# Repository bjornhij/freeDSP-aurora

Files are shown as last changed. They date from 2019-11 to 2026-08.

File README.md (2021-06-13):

FreeDSP logo

# freeDSP aurora

An open source and open hardware [freeDSP](https://freedsp.github.io) board based on ADAU1452 with 8 analog I/O, S/P-DIF I/O, ADAT I/O, USB Audio, WiFi, Bluetooth.

It supports various and convenient physical addons and multiple software plugins, and is controlled by web interface.

## Main features

* Analog Devices ADAU1452, 294.912 MHz, 32-bit SigmaDSP
	* 6144 SIMD instructions per sample @ 48kHz fs
	* 40kWords of data RAM
	* 800ms digital audio delay pool @ 48kHz fs
	* 8 stereo ASRCs with 139dB DNR
* XMOS XE216-512-TQ128 for multichannel bidirectional audio streaming
* ESP32 for WiFi or Bluetooth control
* AKM AK4458 32bit-DAC
* AKM AK5558 32bit-ADC
* Supporting sample rates between 44.1kHz and 192kHz
* 8 analog balanced input channels, +6dBu
* 8 analog balanced output channels, +6dBu
* S/P-DIF input and output
* ADAT input and output
* Wordclock input and output
* Support for display, rotary encoder, volume potentiometer, temperature sensor, PWM controlled fan, IR sensor
* One freeDSP expansion header
* USB Audio Class 2 Bidirectional streaming with 8 channels in and 8 channels out, full-duplex. Works with ASIO driver under Windows 10 and driverless under macOS and Linux.
* Realtime control software over WiFi or Bluetooth available under an open source license
* THD DAC: -103dB @ 1kHz, 0dBfs, fs=48kHz
* THD ADC: -101dB @ 1kHz, 0dBfs, fs=48kHz
* Latency: 1.125ms (talkthrough ADC->DSP->DAC)
* Board dimensions: 110mm x 110mm

MAIN COORDINATOR: [dspverden](https://github.com/dspverden)

## Contributing

**Please take care on which branch you're currently working!**

Branches:

- *master* - this branch always holds the latest released revision
- *develop* - this is the develop branch with new features. Please base your patches on this branch.

[Build instructions](BUILDING.md) | [Addons](ADDONS/README.md) | [User Documentation](DOCUMENTATION/)

## License
<br />This work is licensed under a <a rel="license" href="http://creativecommons.org/licenses/by-sa/4.0/">Creative Commons Attribution-ShareAlike 4.0 International License</a>.

## Links

- [Buy Aurora board and addons](https://auverdion.de/)
- [freeDSP](https://freedsp.github.io)
- [Kickstarter campaign](https://www.kickstarter.com/projects/auverdion/freedsp-aurora-dsp)
- [DIYAudio forum (english)](https://www.diyaudio.com/forums/digital-line-level/334055-freedsp-aurora-dsp-8-os-usb-audio-dif-adat-bluetooth-wifi-contro.html)
- [DIYHifi forum (german, features)](https://www.diy-hifi-forum.eu/forum/showthread.php?18572-freeDSP-aurora-Der-Feature-Thread)
- [DIYHifi forum (german, specs)](https://www.diy-hifi-forum.eu/forum/showthread.php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)
- [Youtube tutorials](https://www.youtube.com/channel/UCGmSGSIjvFPSlGyMbqJgFxw)
- [ADAU1452 at Analog Devices](https://www.analog.com/en/products/adau1452.html)
- [ESP32 at Espressif](https://www.espressif.com/en/products/socs/esp32/overview)
- [XMOS XE216-512-TQ128 datasheet](https://www.xmos.com/file/xe216-512-tq128-datasheet)
- [AKM 4458](https://www.akm.com/us/en/products/audio/audio-dac/ak4458vn/)
- [AKM 5558](https://www.akm.com/us/en/products/audio/audio-adc/ak5558vn/)

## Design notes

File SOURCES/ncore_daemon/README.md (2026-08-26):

# Ncore / aurora daemon

Python-brug tussen de freeDSP aurora (serieel), Hypex Ncore (GPIO), het scherm, en Home Assistant. Geen Volumio, geen Docker. Home Assistant draait **elders**; deze Pi 4 toont de UI fullscreen en bedient de amp.

## Kale installatie (Raspberry Pi 4)

### 1. Imager

Raspberry Pi Imager, **Raspberry Pi OS (64-bit) met desktop** (niet Lite — Chromium-kiosk heeft een GUI nodig):

- hostname: `hypex-amp`
- SSH aan
- gebruiker: `ncore` (niet `volumio`)
- wifi of ethernet

Eerste boot:

```bash
sudo apt update && sudo apt full-upgrade -y
sudo raspi-config
```

In raspi-config: **System Options → Auto Login** (desktop). **I2C niet aanzetten** als AMPON op BCM 3 blijft: dat is I2C1 SCL (`GPIO3`).

### 2. Code en service

Kopieer deze map naar `/home/ncore/ncore_daemon` (git clone van de repo en `cd SOURCES/ncore_daemon`, of rsync).

```bash
cd /home/ncore/ncore_daemon
chmod +x scripts/install.sh scripts/ha-kiosk.sh
./scripts/install.sh
```

Dat zet een venv, `config.yaml`, systemd `ncore-daemon` en Chromium-kiosk autostart. Log daarna opnieuw in zodat de groepen `gpio`, `dialout`, `input` en `video` gelden.

### 3. Scherm herkennen

Op een draaiende Pi (ook de oude):

```bash
cat /proc/device-tree/model; echo
ls /sys/class/backlight/
ls /sys/class/drm/
grep -hE 'dtoverlay|display|hdmi|dsi|lcd' /boot/firmware/config.txt /boot/config.txt 2>/dev/null
```

- Map `rpi_backlight` = official 7" DSI. **Dit is de huidige hypex-amp** (Pi 4B 1.2). Amp aan zet backlight op 80, amp uit op 0.
- `hdmi_force_hotplug=1` kan naast DSI in config.txt staan (tweede HDMI of oude workaround). Ontbreekt `rpi_backlight`, dan HDMI via `vcgencmd display_power`.
- Geen `/sys/class/drm/` op oude Volumio/legacy-graphics is normaal; op verse Pi OS desktop bestaat die map wél.

### 4. Hardware in `config.yaml`

**Serial (aurora)** — niet het Mac-pad `/dev/tty.MALS`:

```bash
ls /dev/serial/by-id /dev/ttyUSB* 2>/dev/null
```

Zet `serial_port` op de `by-id`-symlink (blijft gelijk na reboot).

**IR:**

```bash
python3 - <<'PY'
from evdev import InputDevice, list_devices
for path in list_devices():
    d = InputDevice(path)
    print(path, d.name)
PY
```

Zet `ir_device_name` op een uniek stuk van die naam. USB-IR verschijnt vanzelf; GPIO-IR: `dtoverlay=gpio-ir` in `/boot/firmware/config.txt`.

**GPIO:** BCM 3, HIGH = amp uit. Eerste keer `dry_run: true` of speakers los tot de pin klopt.

**Home Assistant:**

```yaml
ha_kiosk_url: "http://homeassistant.local:8123"
ha_webhook_url: "http://homeassistant.local:8123/api/webhook/ncore_updated"
```

Kiosk-login eenmalig in Chromium. Als het scherm leeg blijft op Wayland: raspi-config → Advanced → Wayland → **X11**, reboot.

```bash
sudo systemctl restart ncore-daemon
curl -s http://127.0.0.1:9090/status
```

`serial_ok` / `gpio_ok` / `ir_ok` moeten kloppen. Debug-UI: `http://hypex-amp.local:9090/`.

## Home Assistant (op de server)

Kopieer `homeassistant/ncore_amp.yaml` naar `configuration.yaml`. Webhook-id: `ncore_updated`. Entiteit: `media_player.ncore_amp` (aan/uit, volume, bron — geen muziekstreaming).

### Kiosk-login (eenmaal, of nooit)

Chromium bewaart de sessie in `~/.config/chromium`. Eerste keer: aparte HA-user `kiosk` (geen admin), inloggen, **Keep me logged in**.

Zonder login-scherm: trusted networks + één user voor het Pi-IP. Alleen `allow_bypass_login` zonder `trusted_users` logt automatisch in als er **één** HA-user is; bij meerdere users krijg je een keuzelijst. Koppel het IP daarom aan het kiosk-user-id:

```yaml
homeassistant:
  auth_providers:
    - type: trusted_networks
      trusted_networks:
        - 192.168.1.50/32
      trusted_users:
        192.168.1.50:
          - 0123456789abcdef0123456789abcdef
      allow_bypass_login: true
    - type: homeassistant
```

User-id: Instellingen → Personen → user openen; id staat in de URL (`/config/users/<id>`). `homeassistant` als tweede provider laten staan, anders kun je vanaf andere IP’s niet meer met wachtwoord inloggen. Daarna HA herstarten.

Niet het Chromium-profiel wissen en niet als admin in de kiosk inloggen.

## Volume-bescherming

- Harde cap `max_volume` (80). HA 100% = die cap.
- Boot: amp uit, DSP naar `power_on_volume` (9).
- Power-on: `min(laatste volume, power_on_restore_cap)` (20) naar de DSP, **daarna** GPIO aan.
- Power-off: eerst mute op de DSP, dan GPIO uit (en scherm uit).
- Omhoog alleen in stappen van 1 (`volume_step_interval_ms` 150). IR-repeat 150 ms.
- Volume 0 stuurt wel mute naar de DSP.

## Dry-run / tests (Mac)

```bash
python3 -m ncore_daemon --dry-run
pip install -r requirements-dev.txt
python -m pytest
```

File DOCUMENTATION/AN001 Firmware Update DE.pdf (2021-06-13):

# FIRMWARE UPDATE FREEDSP-AURORA

auverdion | 1

## REVISIONSÜBERSICHT

Revision | Beschreibung | Datum
v1.0.0 | Initial Version | 09 Feb 2020
v1.1.0 | WebOTA hinzugefügt | 26 Feb 2020
v2.1.0 | Empfehlung zum Presetexport hinzugefügt | 20 Jul 2020
auverdion | 2

Revisionsübersicht | 2
Wichtige Information | 4
Update der Firmware via USB | 5
Update vorbereiten | 5
Firmware hochladen | 6
Update der Firmware über webOTA | 12
Hochladen der Firmware | 12
Haftungsausschluss | 14
auverdion | 3

## WICHTIGE INFORMATION

Das freeDSP-Aurora-Board kann Signale erzeugen, die Dein Audiogerät beschädigen können. Bitte lies dieses Application Note und das Handbuch sorgfältig, bevor Du mit der Arbeit mit Deinem Board beginnst. Passe alle Hardware-Einstellungen an und konfiguriere Deine Software, bevor Du ein Audiogerät an freeDSP-aurora anschließt. Beginne immer mit der geringsten Lautstärke an Deinem Verstärker und erhöhe den Pegel langsam, um das Risiko einer Beschädigung Deines Audiosystems zu verringern.

Insbesondere die Installation von Alpha- und Betaversionen kann zu einem fehlerhaften Verhalten führen. Die Installation erfolgt auf eigenes Risiko.

FreeDSP-aurora wird Dir wie gesehen zur Verfügung gestellt. Auverdion gibt keine ausdrücklichen oder stillschweigenden Garantien in Bezug auf seine Funktionalität, Funktionsfähigkeit oder Nutzung, einschließlich, aber nicht beschränkt auf stillschweigende Garantien der Marktgängigkeit, der Eignung für einen bestimmten Zweck oder Rechtsverletzungen. Wir lehnen ausdrücklich jegliche Haftung für direkte, indirekte, Folge-, Neben- oder Sonderschäden ab, einschließlich, aber nicht beschränkt auf Umsatzeinbußen, entgangenen Gewinn, Verluste infolge von Betriebsunterbrechungen oder Datenverlust, unabhängig von der Art der Klage oder der Rechtstheorie, nach der die Haftung geltend gemacht werden kann, selbst wenn wir über die Möglichkeit oder Wahrscheinlichkeit solcher Schäden informiert wurden. Funktionen und Spezifikationen können ohne vorherige Ankündigung geändert werden.

Bitte beachte, dass freeDSP-aurora ein Open-Source-Projekt ist. Da freeDSP-aurora sehr flexibel ist, sind viele Anwendungen möglich. Fragen und neue Ideen können online mit anderen Nutzern diskutiert werden. Bitte verwende das Digital Line Level Subforum @ diyAudio.com oder das auverdion Subforum @ www.diy-hifi-forum.eu, um mit anderen Personen in Kontakt zu treten, die mit freeDSP-aurora arbeiten. Bitte erstelle nur dann individuelle Themen für Dein Anliegen, wenn Du Dein Problem in den vorhandenen Themen nicht findest. Einige Fragen können durch sorgfältiges Lesen dieses Handbuchs beantwortet werden.

auverdion | 4

## UPDATE DER FIRMWARE VIA USB

Dieses Kapitel führt Dich durch alle Schritte, um ein Firmwareupdate über eine USB-Verbindung durchzuführen. Das Update selbst wird durch ein Skript durchgeführt.

UPDATE VORBEREITEN

Für das Aktualisieren der Firmware benötigst Du ein USB2Serial-Modul basierend auf einem FTx232- oder CP2102N-Modul, z.B. https://www.ftdichip.com/Products/Modules/DevelopmentModules.htm#FT2232H_Mini oder ähnlich. Bitte vergewissere Dich, daß Dein Modul mit einer Spannung von 3.3V arbeitet. Module mit +5V Spannung können Deinen freeDSP-Aurora beschädigen.
Ggfs. Musst Du noch einen Treiber für Dein USB2Serial-Modul installieren. Bitte lies hierzu das Handbuch Deines Moduls.

Wenn Du ein Update von Version 2.x.x ausführen willst, exportiere bitte zunächst Deine Presets, damit Du diese nach dem Update wieder importieren kannst.

auverdion | 5

FIRMWARE HOCHLADEN

Um eine neue Firmware auf Deinen freeDSP-Aurora hochzuladen, gehe wie folgt vor:
1. Lade das neueste Release von github: https://github.com/freeDSP/freeDSP-aurora Wenn Du eine Alpha- oder Betaversion (Preview-Versionen) installieren möchtest, musst Du eventuell in den entsprechenden Featurezweig wechseln, indem Du diesen im Dropdown-Menu Branch auswählst, z.B. feature/develop und anschliessend auf Clone or download klickst und Download ZIP auswählst.

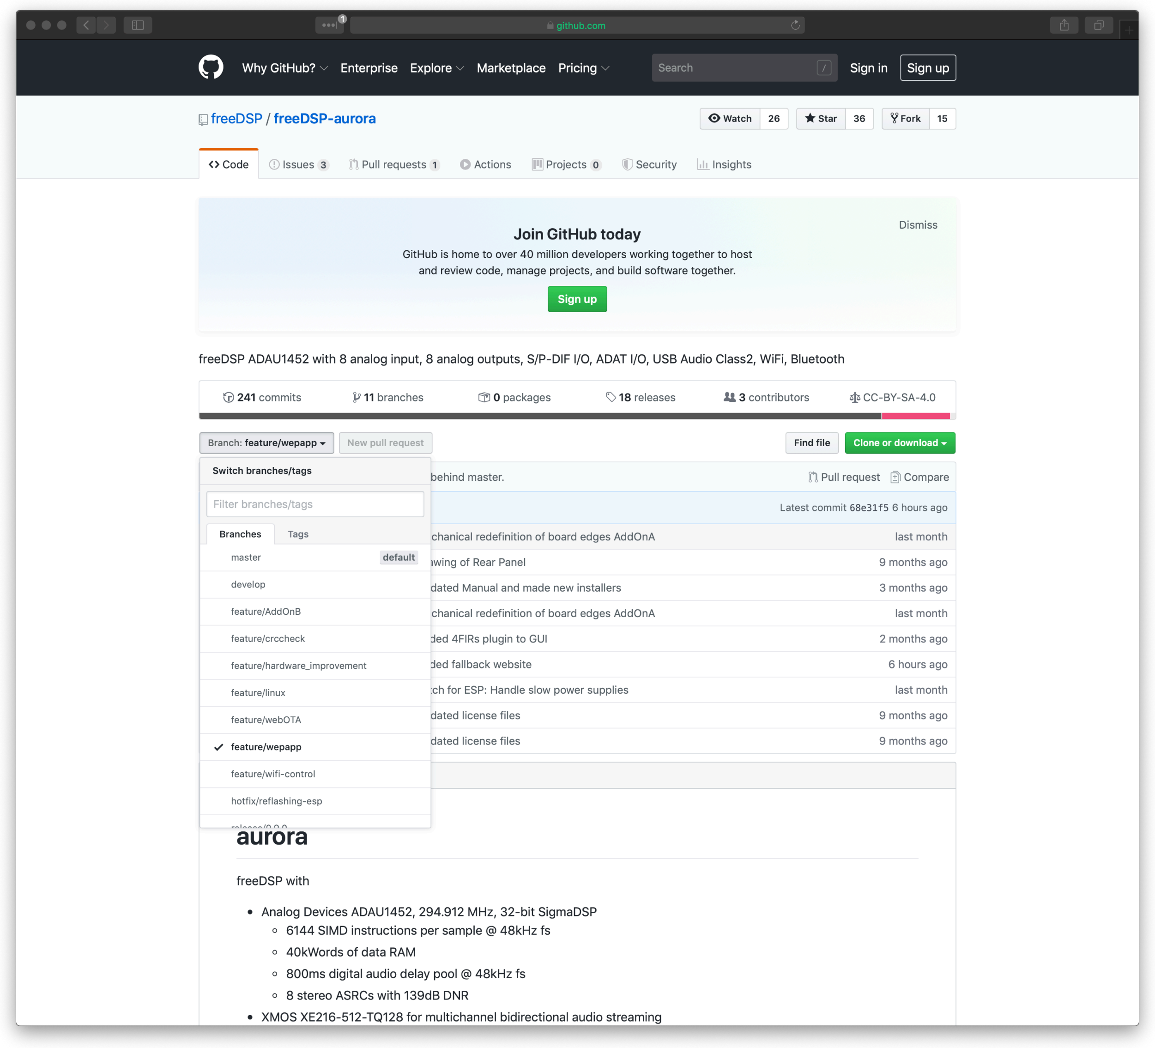
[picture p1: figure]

auverdion | 6

2. Entpacke die heruntergeladene zip-Datei (sofern Dein Computer dies nicht selbstständig erledigt).
3. Schalte Deinen freeDSP-aurora aus.
4. Installiere einen Jumper oder stelle eine Verbindung zwischen Pin 5 und 6 von X504 her. Das Update-Tool wird Dich an diesen Jumper erinnern.

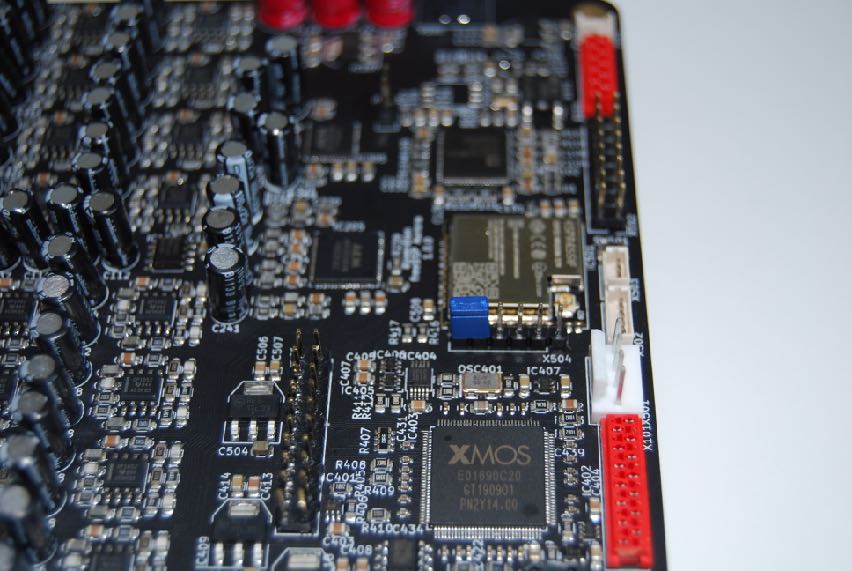
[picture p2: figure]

auverdion | 7

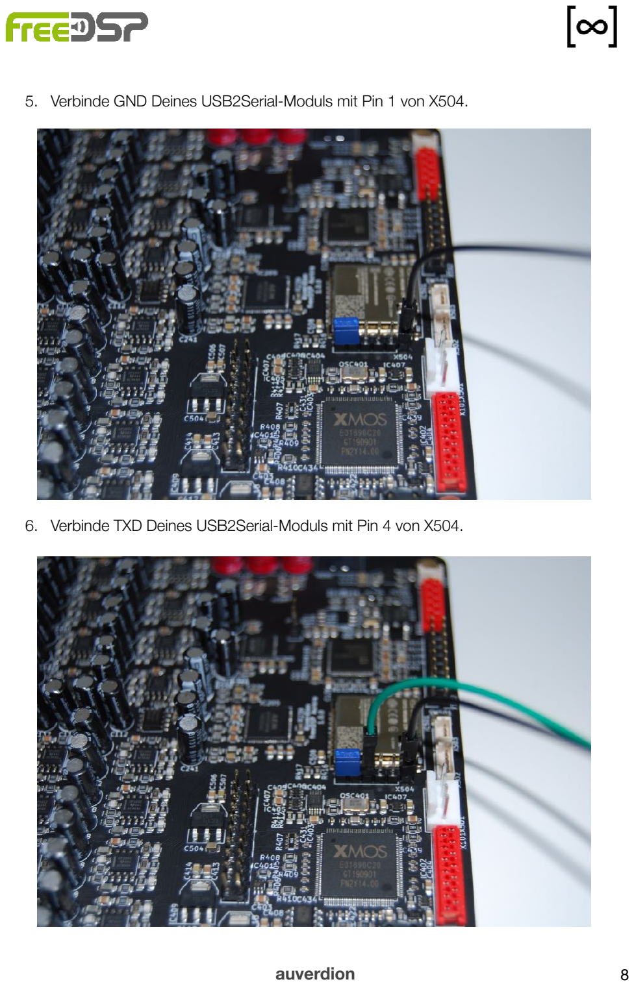
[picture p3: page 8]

5. Verbinde GND Deines USB2Serial-Moduls mit Pin 1 von X504.
6. Verbinde TXD Deines USB2Serial-Moduls mit Pin 4 von X504.
auverdion | 8

7. Verbinde RXD Deines USB2Serial-Moduls mit Pin 3 von X504.

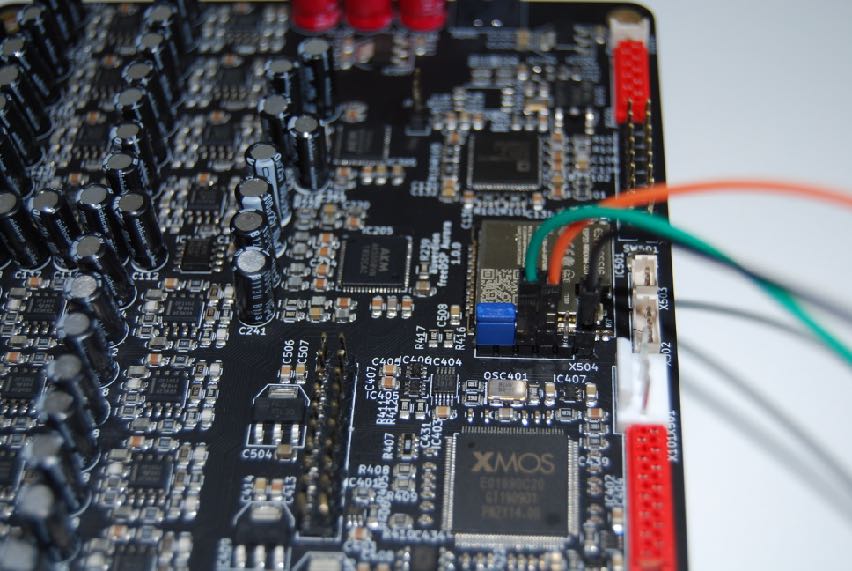
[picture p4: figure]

8. Verbinde Dein USB2Serial-Modul mit Deinem Computer.
9. Schalte freeDSP-Aurora ein.
10. Öffne ein Terminal (Eingabeaufforderung) and wechsle in das Skript-Verzeichnis durch Eingabe von
cd <path_to_repository>/SOURCES/WEBAPP/ESP32/updater
11. Unter macOs kann es sein, dass Du das Updateskript ausführbar machen musst. Gibt dazu ein:
chmod +x update.sh
12. Unter macOS starte das Skript mit ./update.sh <your_com_port>.
Dabei musst Du <your_com_port> durch den Namen Deines USB2Serial-Adapters
ersetzen, z.B. /dev/cu.usbserial-FTRXGG930.
13. Unter Windows gibts Du update.bat <your_com_port> ein.
Dabei musst Du <your_com_port> durch den Namen Deines USB2Serial-Adapters ersetzten, z.B. COM3.
auverdion | 9

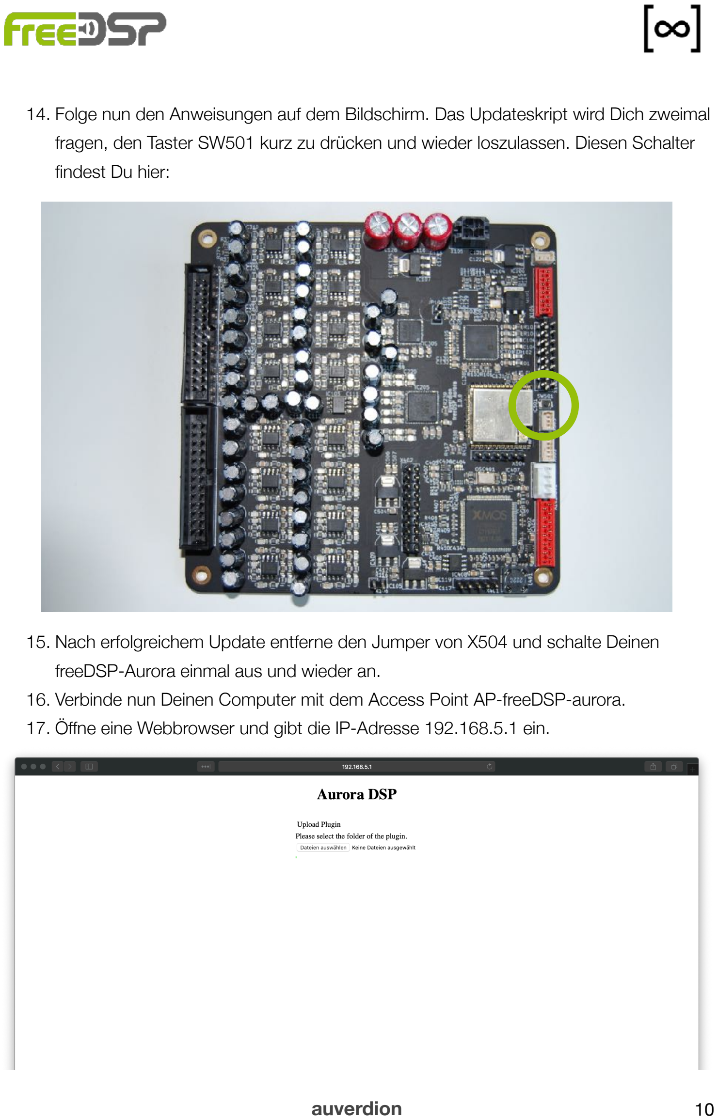
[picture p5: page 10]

14. Folge nun den Anweisungen auf dem Bildschirm. Das Updateskript wird Dich zweimal fragen, den Taster SW501 kurz zu drücken und wieder loszulassen. Diesen Schalter findest Du hier:
15. Nach erfolgreichem Update entferne den Jumper von X504 und schalte Deinen freeDSP-Aurora einmal aus und wieder an.
16. Verbinde nun Deinen Computer mit dem Access Point AP-freeDSP-aurora.
17. Öffne eine Webbrowser und gibt die IP-Adresse 192.168.5.1 ein.
auverdion | 10

18. Klicke nun auf Dateien auswählen und wähle das Verzeichnis mit Deinem Plugin aus. Wichtig: Bitte wähle nur das Verzeichnis, nicht eine Datei in dem Verzeichnis.
Du findest die Plugins im Verzeichnis <path_to_repository>/SOURCES/

WEBAPP/plugins

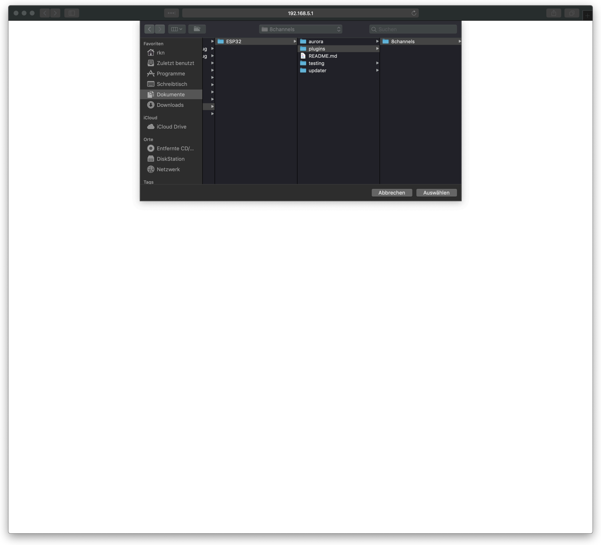
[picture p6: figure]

19. Es wird das gewählte Plugin installiert.
20. Nach erfolgreichem Update startest Du Deinen freeDSP-Aurora neu, verbindest Dich mit dem Access Point AP-freeDSP-aurora und gibst die Adresse 192.168.5.1 in Deinem Webbrowser ein. Du siehts nun das Webinterface Deines gewählten Plugins und kannst damit beginnen, freeDSP-Aurora für Deine Anwendung zu konfiguriere.
auverdion | 11

## UPDATE DER FIRMWARE ÜBER WEBOTA

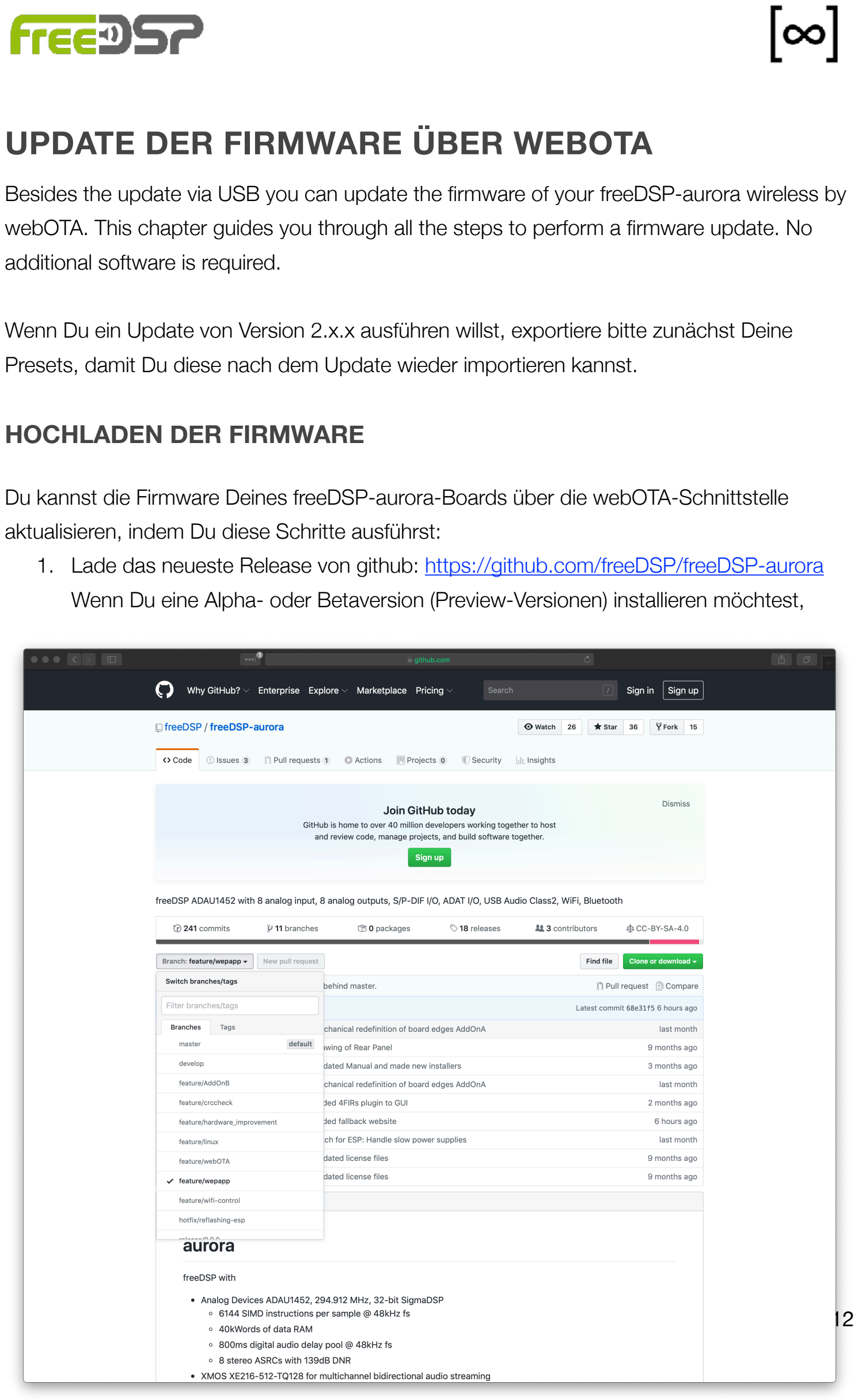
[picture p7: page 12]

Besides the update via USB you can update the firmware of your freeDSP-aurora wireless by webOTA. This chapter guides you through all the steps to perform a firmware update. No additional software is required.

Wenn Du ein Update von Version 2.x.x ausführen willst, exportiere bitte zunächst Deine Presets, damit Du diese nach dem Update wieder importieren kannst.

HOCHLADEN DER FIRMWARE

Du kannst die Firmware Deines freeDSP-aurora-Boards über die webOTA-Schnittstelle aktualisieren, indem Du diese Schritte ausführst:
1. Lade das neueste Release von github: https://github.com/freeDSP/freeDSP-aurora Wenn Du eine Alpha- oder Betaversion (Preview-Versionen) installieren möchtest,
auverdion | 12

musst Du eventuell in den entsprechenden Featurezweig wechseln, indem Du diesen im Dropdown-Menu Branch auswählst, z.B. feature/develop und anschliessend auf Clone or download klickst und Download ZIP auswählst. Die heruntegeladene ZIP-Datei musst Du noch entpacken, falls Dein Computer das nicht selbständig macht.
2. Verbinde Deinen Computer mit dem WiFi-Access-Point AP-freeDSP-aurora.
3. Öffne einen Webbrowser und gib die URL http://192.168.5.1/webota ein.
4. Alternativ kannst Du Deinen Computer mit dem gleichen lokalen WiFi-Netzwerk verbinden, mit dem auch Dein freeDSP-Aurora verbunden ist, und die IP 192.168.5.1 durch die IP ersetzen, die Dein Board von Deinem Router erhalten hat.
5. Klicke auf die Schaltfläche, um die Firmware-Binärdatei von Ihrer Festplatte auszuwählen. Der Dateiname der Firmware ist üblicherweise
aurora.ino.esp32.bin. Die Firmware auf dem neuesten Stand findest Du in

<path_to_repository>/SOURCES/WEBAPP/ESP32/updater
6. Sobald Du eine Datei ausgewählt hast wird die neue Firmware auf Dein Board hochgeladen. Nach dem erfolgreichen Update erhältst Du eine Benachrichtigung und Dein freeDSP-aurora-Board wird anschliessend automatisch neu gestartet.
7. Verbinde Dich mit dem Access Point AP-freeDSP-aurora und gebe http://192.168.5.1/fallback im URL-Feld Deines Browsers ein.
8. Installiere nun das Plugin neu.
9. Dein freeDSP-aurora ist nun auf dem neuesten Stand.
auverdion | 13

## HAFTUNGSAUSSCHLUSS

Alle Produkte, Produktspezifikationen und Daten können ohne Vorankündigung geändert werden, um die Zuverlässigkeit, Funktion oder das Design zu verbessern.
Auverdion, seine Tochtergesellschaften, Vertreter und Mitarbeiter sowie alle Personen, die in seinem oder ihrem Namen handeln, lehnen jegliche Haftung für Fehler, Ungenauigkeiten oder Unvollständigkeiten ab, die in einem Datenblatt, Handbuch, einer Anwendungsnotiz oder einem anderen Dokument zu einem Produkt enthalten sind.
Diese Baugruppe ist nur für den Einsatz in Musikwiedergabegeräten vorgesehen. Es werden keine Angaben zur Eignung für andere Zwecke gemacht. Sofern nicht anders angegeben, beziehen sich die angegebenen Spezifikationen nur auf diese Baugruppe. Die Verantwortung für die Überprüfung der Leistung, Sicherheit, Zuverlässigkeit und Einhaltung der gesetzlichen Normen von Endprodukten mit dieser Baugruppe liegt beim Hersteller des Endprodukts.

Auverdion gibt keine ausdrücklichen oder stillschweigenden Garantien in Bezug auf seine Funktionalität, Funktionsfähigkeit oder Nutzung, einschließlich, aber nicht beschränkt auf stillschweigende Garantien der Marktgängigkeit, der Eignung für einen bestimmten Zweck oder Rechtsverletzung. Wir lehnen ausdrücklich jegliche Haftung für direkte, indirekte, Folge-, Neben- oder Sonderschäden ab, einschließlich, aber nicht beschränkt auf Umsatzeinbußen, entgangenen Gewinn, Verluste infolge von Betriebsunterbrechungen oder Datenverlust, unabhängig von der Art der Klage oder der Rechtstheorie, nach der die Haftung geltend gemacht werden kann, selbst wenn wir über die Möglichkeit oder Wahrscheinlichkeit solcher Schäden informiert wurden.

Die Verwendung von Auverdion-Produkten in lebenserhaltenden Geräten oder Geräten, deren Ausfall erwartbar zu Verletzungen oder zum Tod führen kann, ist nicht zulässig.

auverdion | 14

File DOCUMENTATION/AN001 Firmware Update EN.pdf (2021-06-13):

# FIRMWARE UPDATE FREEDSP-AURORA

auverdion | 1

## REVISION HISTORY

Revision | Description | Date
v1.0.0 | Initial Version | 09 Feb 2020
v1.1.0 | Added webOTA | 26 Feb 2020
v2.1.0 | Added hint for preset export | 20 Jul 20
auverdion | 2

Revision History | 2
Important Information | 4
Updating the Firmware via USB | 5
Preparing for Update | 5
Uploading the Firmware | 6
Updating the Firmware via webOTA | 12
Uploading the Firmware | 12
Disclaimer | 14
auverdion | 3

## IMPORTANT INFORMATION

The freeDSP-aurora board might generate signals that may damage your audio equipment. Please read and understand this manual before starting to work with your board. Adjust all hardware settings and configure your software before connecting any audio equipment to freeDSP-aurora. Always start with low volume on your amplifier and slowly increase the level to reduce the risk of damaging your audio system.

Especially the installation of alpha and beta versions can lead to incorrect behavior. The installation is at your own risk.

freeDSP-aurora is provided to you ‘as is’. Auverdion makes no express or implied warranties whatsoever with respect to its functionality, operability, or use, including, without limitation, any implied warranties of merchantability, fitness for a particular purpose, or infringement. We expressly disclaim any liability whatsoever for any direct, indirect, consequential, incidental or special damages, including, without limitation, lost revenues, lost profits, losses resulting from business interruption or loss of data regardless of the form of action or legal theory under which the liability may be asserted, even if advised of the possibility or likelihood of such damages. Features and specifications might change without prior notice.

Please keep in mind that freeDSP-aurora is an open-source project. Because freeDSP-aurora is very flexible, many applications are possible. Questions and new ideas can be discussed online with other DIYers. Please use the Digital Line Level subforum @ diyAudio.com or the auverdion subforum @ www.diy-hifi-forum.eu to connect with other people working with freeDSP-aurora. Please create individual threads for your topics only if you cannot find your issue in the existing threads. Some questions can be answered by carefully reading this manual.

auverdion | 4

## UPDATING THE FIRMWARE VIA USB

This chapter guides you through all the steps to perform a firmware update via an USB connection. The update itself will be done by a script.

PREPARING FOR UPDATE

For updating the firmware you need an USB2Serial module based on a FTx232 or CP2102N module, e.g.
https://www.ftdichip.com/Products/Modules/DevelopmentModules.htm#FT2232H_Mini or similar. Please make sure that your module works with a voltage of +3.3V. Modules with +5V voltage can damage your freeDSP-Aurora.
You may need to install a driver for your USB2Serial module. Please read the manual of your module.

If you are updating from version 2.x.x please export your presets first and import them after the update again.

auverdion | 5

UPLOADING THE FIRMWARE

For uploading a new firmware to your freeDSP-aurora do the following steps:
1. Download the latest release from github: https://github.com/freeDSP/freeDSP-aurora If you want to install a alpha or beta version (preview versions) instead you may have to switch to the right feature branch by selecting it in the branch drop down menu, e.g. feature/develop. Then click on Clone or download and select Download ZIP.

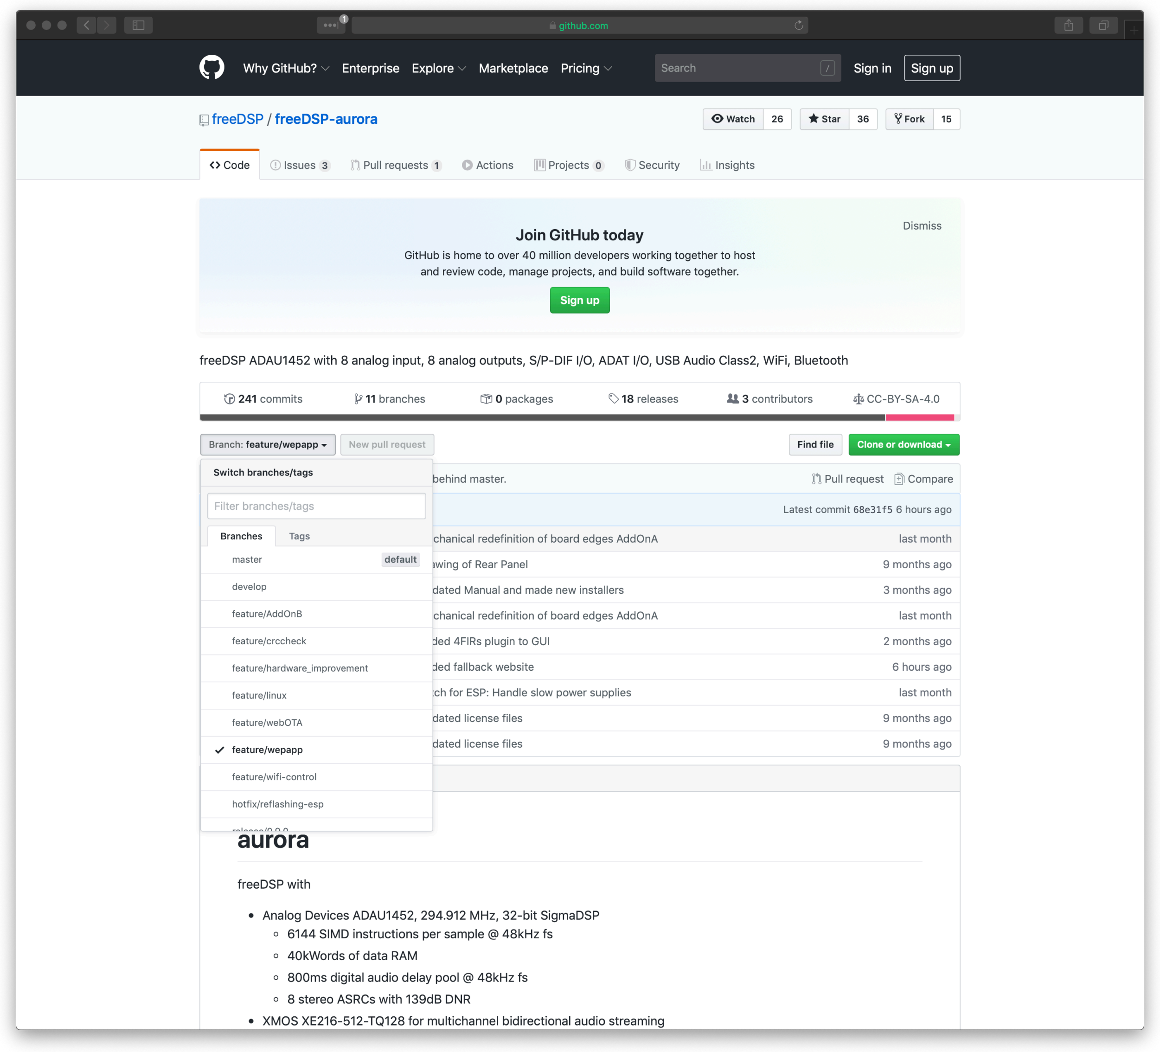
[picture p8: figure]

2. Unzip the downloaded zip file (if your computer does not do this by itself).
3. Power off your freeDSP-aurora module.
auverdion | 6

4. Install a jumper or make a connection between pin 5 and 6 of X504. The update tool will remind you of this jumper.


auverdion | 7

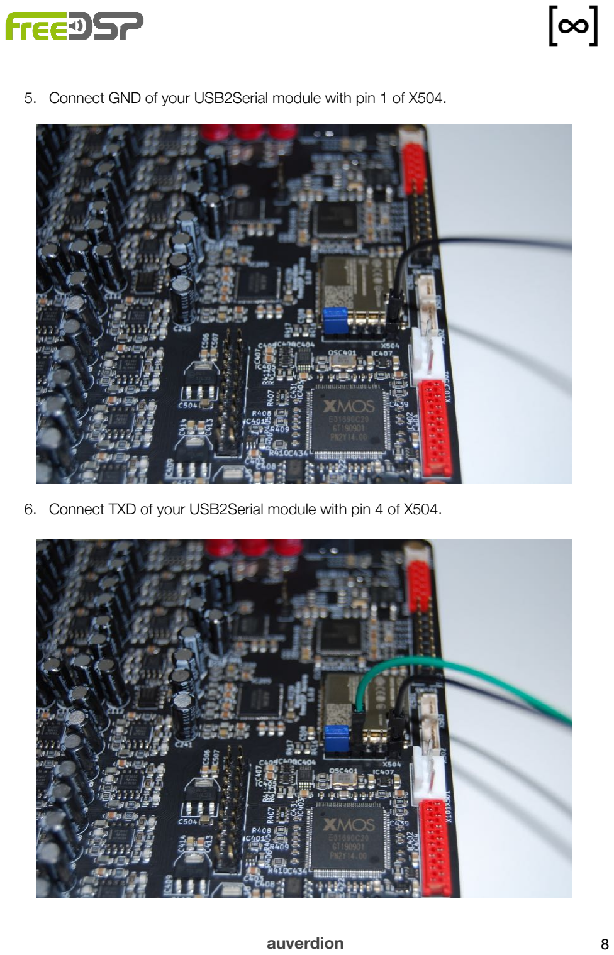
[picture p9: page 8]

5. Connect GND of your USB2Serial module with pin 1 of X504.
6. Connect TXD of your USB2Serial module with pin 4 of X504.
auverdion | 8

7. Connect RXD of your USB2Serial module with pin 3 of X504.


8. Connect your USB2Serial module with your computer.
9. Power up your freeDSP-aurora.
10. Open a terminal (command prompt) and change to script directory by entering
cd <path_to_repository>/SOURCES/WEBAPP/ESP32/updater
11. On macOs you may have to make the update script executable by entering
chmod +x update.sh
12. Under macOS start the update scrip by ./update.sh <your_com_port>. Replace <your_com_port> by the name of your USB2Serial module, e.g.
/dev/cu.usbserial-FTRXGG930.
13. Under Windows start the update scrip by update.bat <your_com_port>. Replace <your_com_port> by the name of your USB2Serial module, e.g. COM3.
auverdion | 9

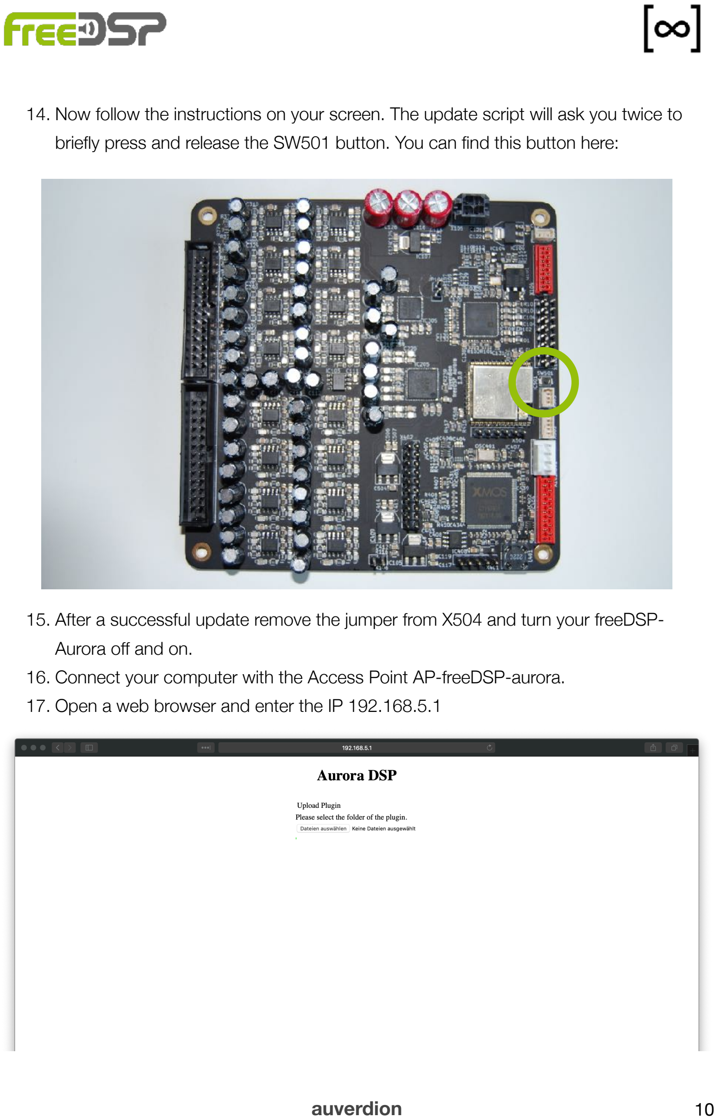
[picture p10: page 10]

14. Now follow the instructions on your screen. The update script will ask you twice to briefly press and release the SW501 button. You can find this button here:
15. After a successful update remove the jumper from X504 and turn your freeDSP-Aurora off and on.
16. Connect your computer with the Access Point AP-freeDSP-aurora.
17. Open a web browser and enter the IP 192.168.5.1
auverdion | 10

18. Click now on Select files and select the directory of the plugin you want to install. Important: You have to select the directory name not any file inside this directory. You
will find the plugins here: <path_to_repository>/SOURCES/WEBAPP/plugins

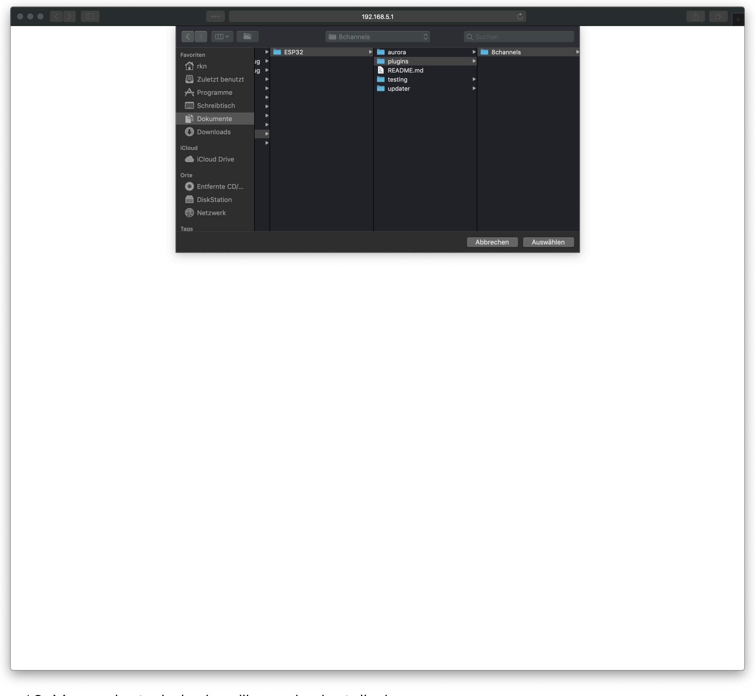
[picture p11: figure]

19. Your selected plugin will now be installed.
20. After successful installation restart your freeDSP-Aurora, reconnect to access point AP-freeDSP-aurora and in your web browser type in the address 192.168.5.1. You will see now the web interface of your selected plugin. You can now start to configure freeDSP-Aurora for your application.
auverdion | 11

## UPDATING THE FIRMWARE VIA WEBOTA

Besides the update via USB you can update the firmware of your freeDSP-aurora wireless by webOTA. This chapter guides you through all the steps to perform a firmware update. No additional software is required.

If you are updating from version 2.x.x please export your presets first and import them after the update again.

UPLOADING THE FIRMWARE

For uploading a new firmware to your freeDSP-aurora do the following steps:
1. Download the latest release from github: https://github.com/freeDSP/freeDSP-aurora If you want to install a alpha or beta version (preview versions) instead you may have

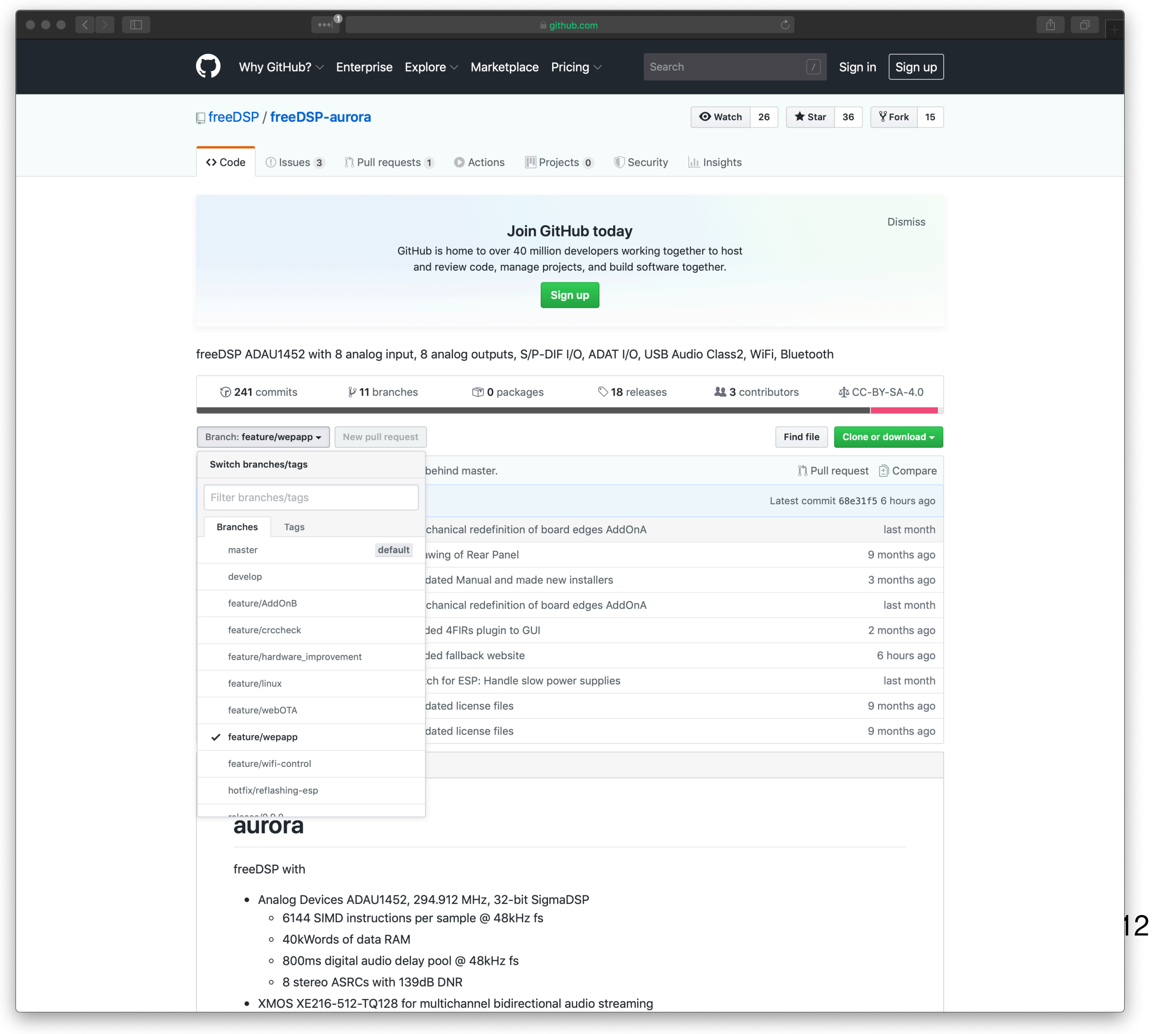
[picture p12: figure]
auverdion

to switch to the right feature branch by selecting it in the branch drop down menu, e.g. feature/develop. Then click on Clone or download and select Download ZIP.
2. Unzip the downloaded zip file (if your computer does not do this by itself).
3. Connect you computer with the WiFi access point AP-freeDSP-aurora.
4. Open web browser and type in the URL http://192.168.5.1/webota
5. Alternatively you can connect you computer to the same local WiFi network your freeDSP-aurora is connected to and replace the ip 192.168.5.1 by the ip your board got from your router.
6. Click on the button to select the firmware binary from your hard disk. The filename of the firmware is usually aurora.ino.esp32.bin. You can find the latest binary in

<path_to_repository>/SOURCES/WEBAPP/ESP32/updater
7. Once you have selected a file the update process starts. The new binary will now be uploaded to your board. After a successful update you will see a message box and afterwards your freeDSP-aurora board will restart.
8. Connect to the Access Point AP-freeDSP-aurora and enter http://192.168.5.1/fallback (http://192.168.5.1/fallback) in the URL field of your browser.
9. Reinstall your plugin now.
10. Your freeDSP-aurora is updated now.
auverdion | 13

## DISCLAIMER

All products, product specifications and data are subject to change without notice to improve reliability, function or design or otherwise.
Auverdion, its affiliates, agents, and employees, and all persons acting on its or their behalf, disclaim any and all liability for any errors, inaccuracies or incompleteness contained in any datasheet, manual, application note or any other document relating to any product.
This subassembly is designed for use in music reproduction equipment only. No representations are made as to fitness for other uses. Except where noted otherwise any specifications given pertain to this subassembly only. Responsibility for verifying the performance, safety, reliability and compliance with legal standards of end products using this subassembly falls to the manufacturer of said end product.

Auverdion makes no express or implied warranties whatsoever with respect to its functionality, operability, or use, including, without limitation, any implied warranties of merchantability, fitness for a particular purpose, or infringement. We expressly disclaim any liability whatsoever for any direct, indirect, consequential, incidental or special damages, including, without limitation, lost revenues, lost profits, losses resulting from business interruption or loss of data regardless of the form of action or legal theory under which the liability may be asserted, even if advised of the possibility or likelihood of such damages.

Life support policy: Use of auverdion products in life support equipment or equipment whose failure can reasonably be expected to result in injury or death is not permitted.

auverdion | 14

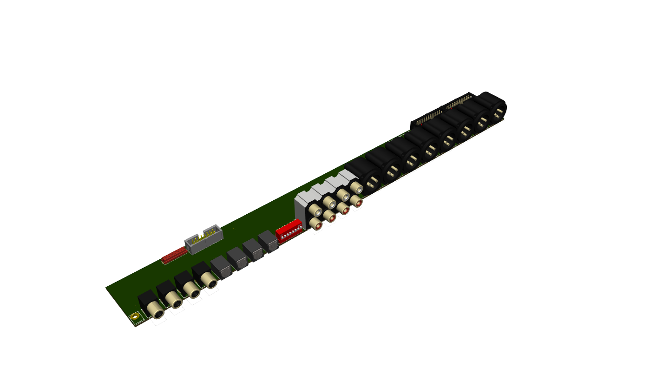
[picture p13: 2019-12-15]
ADDONS/IO/AddOnB-A1.png

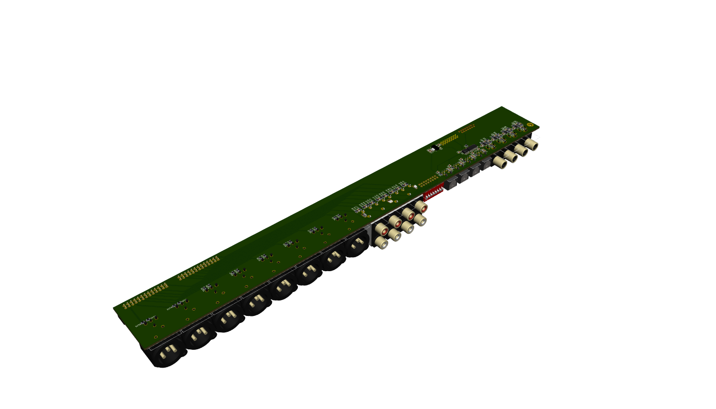
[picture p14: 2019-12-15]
ADDONS/IO/AddOnB-A2.png

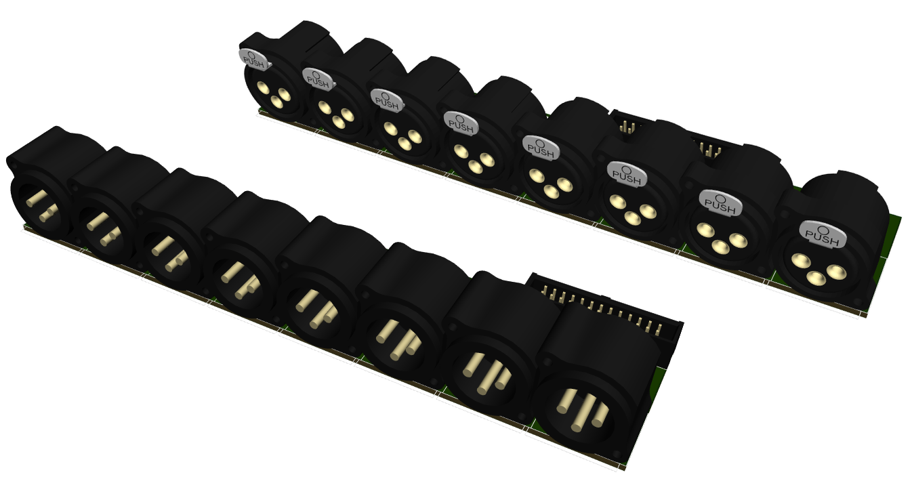
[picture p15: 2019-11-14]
ADDONS/AddOnD/AddOnD_A_B.png

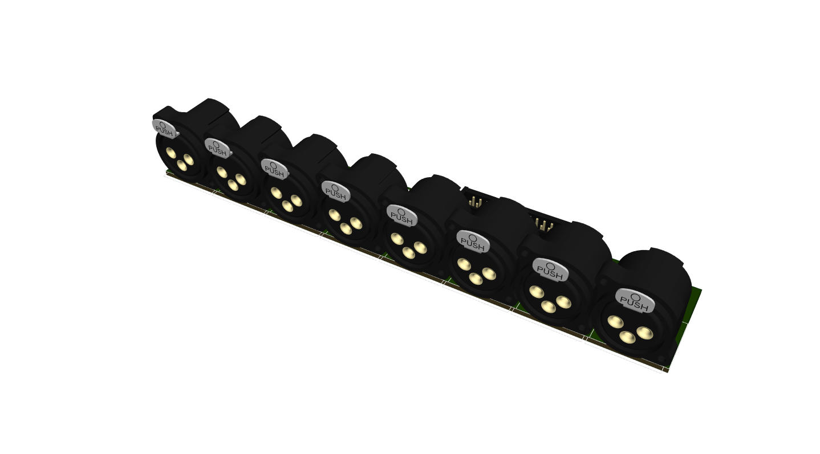
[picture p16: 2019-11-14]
ADDONS/AddOnD/KICAD/Board B/AddOnD.png

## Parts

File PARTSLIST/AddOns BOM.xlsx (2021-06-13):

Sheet: AddOnA
AddOn A rev 1.0.0
Reference | Qty | Footprint | Value1 | Value2 | Manufacturer | pn
B1, B2 | 2 | Montagewinkel
C17 | 1 | C0805-X7R | 10n0 | 10% 50V X7R | Yageo | CC0805KRX7R9BB103
C5, C6, C101 | 3 | C0805-X7R | 100p | 5% 50V C0G/NP0 | Kemet | C0805C101J5GACTU
C1, C2, C3, C4, C7, C24, C109, C113 | 8 | C0805-X7R | 100n | 5% 50V X7R | Kemet | C0805C104K5RACTU
D1 | 1 | D_0603_1608Metric |  |  | Littelfuse Inc. | PESD0603-240
IC1 | 1 | SOT23-5 |  |  | ON Semiconductor | FIN1002M5X
IC6 | 1 | SOIC8_3.9x4.9mm_Pitch1.27mm |  |  | Texas Instruments | PCA9536DR
IC101 | 1 | SOIC-16_3.9x9.9mm_P1.27mm |  |  | Texas Instruments | SN74HC251DR
L101 | 1 | C0805-X7R |  |  | Taiyo Yuden | LBR2012T470K
P1 | 1 | RK09K1110-20 |  |  | Alps | RK09K1110A0J
R1 | 1 | C0805-RES | 91R0 | 1% 0.125W Thick | Yageo | RC0805FR-0791RL
R2 | 1 | C0805-RES | 820R | 1% 0.125W Thick | Yageo | RC0805FR-07820RL
R3, R4, R5 | 3 | C0805-RES | 470R | 1% 0.125W Thick | Yageo | RC0805FR-07470RL
R6, R29 | 2 | C0805-RES | 33R0 | 1% 0.125W Thick | Yageo | RC0805FR-0733RL
R8, R10 | 2 | C0805-RES | 100K | 1% 0.125W Thick | Yageo | RC0805FR-07100KL
R11, R12, R13, R14 | 4 | C0805-RES | 47K0 | 1% 0.125W Thick | Yageo | RC0805FR-0747KL
R25 | 1 | C0805-RES | 10K0 | 1% 0.125W Thick | Yageo | RC0805FR-0710KL
R101, R102 | 2 | C0805-RES | 68R0 | 1% 0.125W Thin | Panasonic Electronic Components | ERA-6AED680V
R7, R9, R117 | 3 | C0805-RES | 100R | 1% 0.25W Thin | Stackpole Electronics Inc | RNCP0805FTD100R
R118 | 1 | C0805-RES | 220K | 1% 0.125W Thick | Yageo | RC0805FR-07220KL
SW1, SW2 | 2 | GEMINI_A |  |  | TE Connectivity Alcoswitch | A203MD9AB04
X1, X3 | 2 | PJRAN1X1U01AUX |  |  | Switchcraft Inc. | PJRAN1X1U01AUX
X2 | 1 | NC3FAH |  |  | Neutrik | NC3FAH1
X4 | 1 | Molex_PicoBlade_530470310 |  |  | Molex | 530470310
X5 | 1 | MM-14G | MicroMatch-14 | - | TE Connectivity AMP Connectors | 1-215079-4
X6 | 1 | IDC2x8_Pitch2.54mm |  |  | On Shore Technology Inc. | 302-S161
X7 | 1 | PLT133_T10W |  |  | Everlight Electronics Co Ltd | PLT133/T10W
X8 | 1 | USB_B | USB_B | horizontal | On Shore Technology Inc. | USB-B1HSB6
X9 | 1 | PinHeader_1x05_P2.54mm_Vertical |  |  | Sullins Connector Solutions | PRPC005SAAN-RC
X101 | 1 | NC3MAH |  |  | Neutrik | NC3MAH-0
X110 | 1 | PLR135_T10 |  |  | Everlight Electronics Co Ltd | PLR135/T10
X114, X115 | 2 | IDC26 | IDC26 |  | Bud Industries | BC-32677

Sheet: AddOnB
AddOn B rev 1.0.0
Reference | Qty | Footprint | Value1 | Value2 | Manufacturer | pn
Board A
C17, C18, C19, C20 | 4 | C0805-X7R | 10n0 | 10% 50V X7R | Yageo | CC0805KRX7R9BB103
C21, C23 | 2 | C0805-X7R | 10u0 | 20% 25V X5R | Murata Electronics North America | GRM21BR61E106MA73L
C101, C102, C103, C104, C105, C106, C107, C108 | 8 | C0805-X7R | 100p | 5% 50V C0G/NP0 | KEMET | C0805C101J5GACTU
C1, C2, C3, C4, C5, C6, C7, C8, C9, C10, C11, C12, C13, C14, C15, C16, C22, C24, C109, C110, C111, C112, C113 | 23 | C0805-X7R | 100n | 5% 50V X7R | KEMET | C0805C104K5RACTU
D1, D2, D3, D4 | 4 | D_0603_1608Metric |  |  | Littelfuse Inc. | PESD0603-240
IC1, IC2, IC3, IC4 | 4 | SOT23-5 |  |  | ON Semiconductor | FIN1002M5X
IC5 | 1 | SOT223 | NCP1117LPST33 |  | ON Semiconductor | NCP1117LPST33T3G
IC6 | 1 | SOIC8_3.9x4.9mm_Pitch1.27mm |  |  | Texas Instruments | PCA9536DR
IC101 | 1 | SOIC-16_3.9x9.9mm_P1.27mm |  |  | Texas Instruments | SN74HC251DR
L101, L102, L103, L104 | 4 | C0805-X7R |  |  | Taiyo Yuden | LBR2012T470K
R1, R7, R13, R19 | 4 | C0805-RES | 91R0 | 1% 0.125W Thick | Yageo | RC0805FR-0791RL
R2, R8, R14, R20 | 4 | C0805-RES | 820R | 1% 0.125W Thick | Yageo | RC0805FR-07820RL
R3, R4, R5, R9, R10, R11, R15, R16, R17, R21, R22, R23 | 12 | C0805-RES | 470R | 1% 0.125W Thick | Yageo | RC0805FR-07470RL
R6, R12, R18, R24, R29 | 5 | C0805-RES | 33R0 | 1% 0.125W Thick | Yageo | RC0805FR-0733RL
R25, R26, R27, R28 | 4 | C0805-RES | 10K0 | 1% 0.125W Thick | Yageo | RC0805FR-0710KL
R101, R102, R103, R104, R105, R106, R107, R108, R109, R110, R111, R112, R113, R114, R115, R116 | 16 | C0805-RES | 68R0 | 1% 0.125W Thin | Panasonic Electronic Components | ERA-6AED680V
R117, R119, R121, R123, R125, R127, R129, R131 | 8 | C0805-RES | 100R | 0.5% 0.100W Thin | Susumu | RR1220P-101-D
R118, R120, R122, R124, R126, R128, R130, R132 | 8 | C0805-RES | 220K | 1% 0.125W Thick | Yageo | RC0805FR-07220KL
SW101 | 1 | KAS2108E |  |  | E-Switch | KAS2108ET
X1, X2, X3, X4 | 4 | PJRAN1X1U01AUX |  |  | Switchcraft Inc. | PJRAN1X1U01AUX
X5 | 1 | MM-14G | MicroMatch-14 |  | TE Connectivity AMP Connectors | 1-215079-4
X6 | 1 | IDC2x8_Pitch2.54mm |  |  | On Shore Technology Inc. | 302-S161
X101, X102, X103, X104, X105, X106, X107, X108 | 8 | NC3MAH |  |  | Neutrik | NC3MAH-0
X109 | 1 | PJRAS4X2U01 |  |  | Switchcraft Inc. | PJRAS4X2U01AUX
X110, X111, X112, X113 | 4 | PLR135_T10 |  |  | Everlight Electronics Co Ltd | PLR135/T10
X114, X115 | 2 | IDC26 | IDC26 |  | Bud Industries | BC-32677
 | 5 |  | IDC26 Connector |  | On Shore Technology Inc. | 101-266
 | 2 |  | IDC16 Connector |  | On Shore Technology Inc. | 101-166
 | 2 |  | MicroMatch-14 Connector |  | TE Connectivity AMP Connectors | 1-215083-4
Board B
C101, C102, C103, C104, C105, C106, C107, C108, C109, C110, C111, C112, C113, C114, C115, C116 | 16 | C0805-X7R | 100p | 5% 50V C0G/NP0 | Kemet | C0805C101J5GACTU
R101, R103, R105, R107, R109, R111, R113, R115, R117, R119, R121, R123, R125, R127, R129, R131 | 16 | C0805-RES | 100R | 0.5% 0.100W Thin | Susumu | RR1220P-101-D
R102, R104, R106, R108, R110, R112, R114, R116, R118, R120, R122, R124, R126, R128, R130, R132 | 16 | C0805-RES | 100K | 1% 0.125W Thick | Yageo | RC0805FR-07100KL
R133, R135, R136, R138, R139, R141, R142, R144, R145, R147, R148, R150, R151, R153, R154, R156 | 16 | C0805-RES | 0R00 | 0.5% 0.125W Thick | Yageo | RC0805JR-070RL
R134, R137, R140, R143, R146, R149, R152, R155 | 8 | C0805-RES | DNP
X101, X102, X103, X104, X105, X106, X107, X108 | 8 | NC3FAH | NC3FAH |  | Neutrik | NC3FAH1
X109 | 1 | IDC26 | IDC26 |  | Bud Industries | BC-32677

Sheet: AddOnD
AddOn D rev 1.0.0
Reference | Qty | Footprint | Value1 | Value2 | Manufacturer | pn
Board A
R101, R102, R103, R104, R105, R106, R107, R108, R109, R110, R111, R112, R113, R114, R115, R116 | 16 | C0805-RES | 68R0 | 1% 0.125W Thin | Panasonic Electronic Components | ERA-6AED680V
X101, X102, X103, X104, X105, X106, X107, X108 | 8 | NC3MAH | NC3MAH |  | Neutrik | NC3MAH-0
X115 | 1 | IDC26 | IDC26 |  | Bud Industries | BC-32677
Board B
C101, C102, C103, C104, C105, C106, C107, C108, C109, C110, C111, C112, C113, C114, C115, C116 | 16 | C0805-X7R | 100p | 5% 50V C0G/NP0 | Kemet | C0805C101J5GACTU
R101, R103, R105, R107, R109, R111, R113, R115, R117, R119, R121, R123, R125, R127, R129, R131 | 16 | C0805-RES | 100R | 1% 0.25W Thin | Susumu | RR1220P-101-D
R102, R104, R106, R108, R110, R112, R114, R116, R118, R120, R122, R124, R126, R128, R130, R132 | 16 | C0805-RES | 100K | 1% 0.125W Thick | Yageo | RC0805FR-07100KL
R133, R135, R136, R138, R139, R141, R142, R144, R145, R147, R148, R150, R151, R153, R154, R156 | 16 | C0805-RES | 0R00 | 0.5% 0.125W Thick | Yageo | RC0805JR-070RL
R134, R137, R140, R143, R146, R149, R152, R155 | 8 | C0805-RES | DNP
X101, X102, X103, X104, X105, X106, X107, X108 | 8 | NC3FAH | NC3FAH |  | Neutrik | NC3FAH1
X109 | 1 | IDC26 | IDC26 |  | Bud Industries | BC-32677

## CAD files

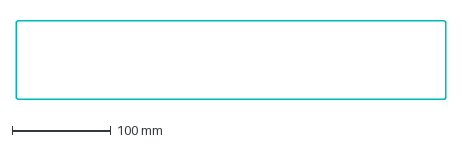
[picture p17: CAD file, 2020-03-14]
ADDONS/AddOnB/Case Plates/2HE Aussenkontur.dxf
435.0 x 80.0 mm

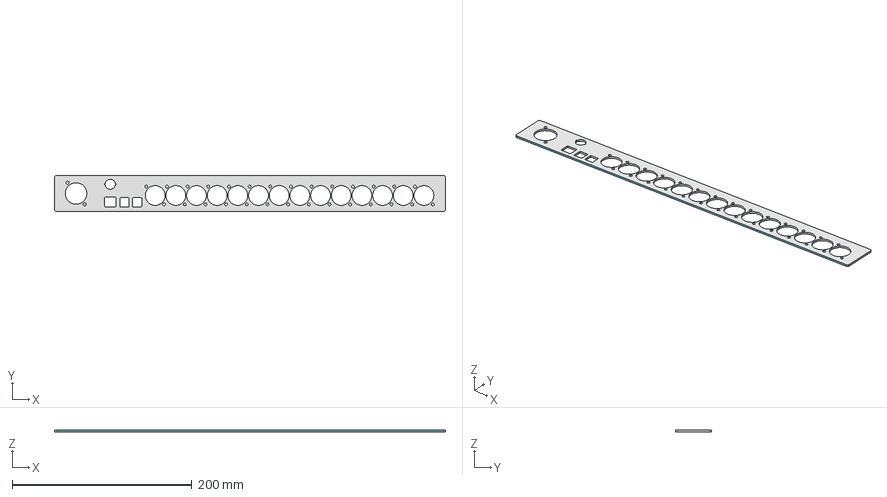
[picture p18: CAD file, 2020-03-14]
ADDONS/AddOnC/Case Plates/Panel-C+Powercon.stp
435.0 x 40.0 x 2.00 mm

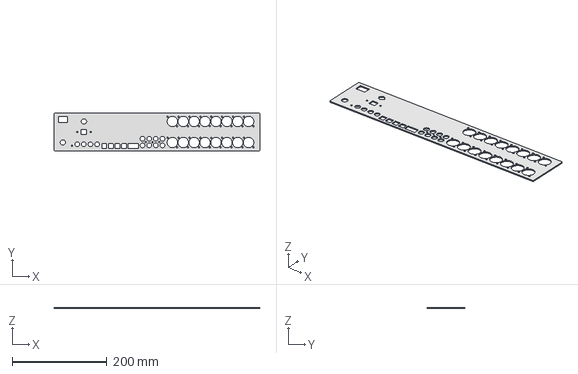
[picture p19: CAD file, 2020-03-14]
ADDONS/AddOnB/Case Plates/Panel-B+12v.stp
435.0 x 80.0 x 2.00 mm

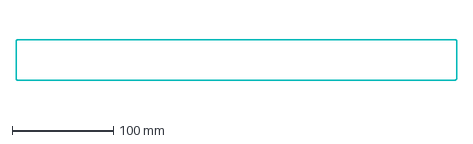
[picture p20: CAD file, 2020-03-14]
ADDONS/AddOnD/Case Plates/Aussenkontur 1HE.dxf
435.0 x 40.0 mm

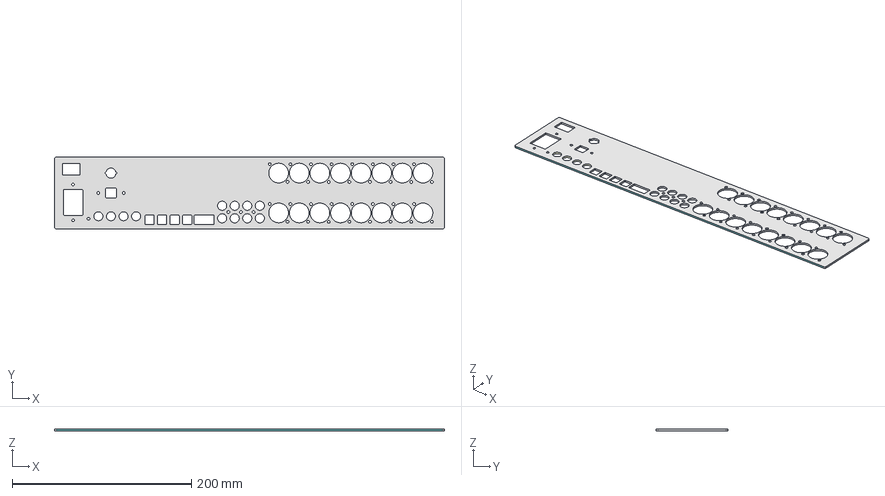
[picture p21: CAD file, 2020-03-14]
ADDONS/AddOnB/Case Plates/Panel-B+Kalt.stp
435.0 x 80.0 x 2.00 mm

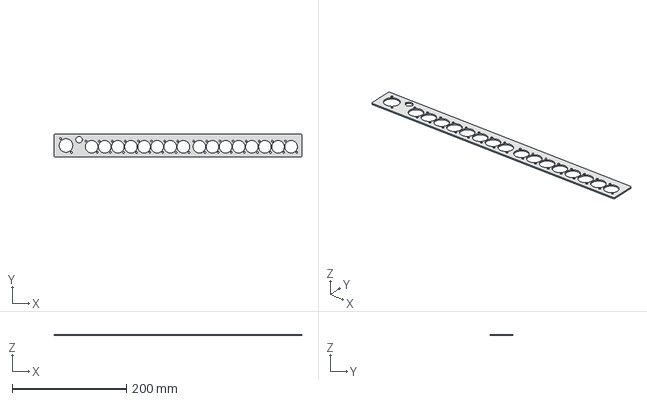
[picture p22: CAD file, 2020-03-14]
ADDONS/AddOnD/Case Plates/Panel-D+Powercon.stp
435.0 x 40.0 x 2.00 mm

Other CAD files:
ADDONS/AddOnD/Case Plates/Panel-D+12v.stp
ADDONS/AddOnC/Case Plates/Panel-C+12v.stp
ADDONS/AddOnC/Case Plates/Panel-C+Kalt.stp
ADDONS/AddOnB/Case Plates/Panel-B+Powercon.stp
ADDONS/AddOnB/Case Plates/Panel-B+12v.dxf
ADDONS/AddOnB/Case Plates/Panel-B+12v.stl
ADDONS/AddOnB/Case Plates/Panel-B+Kalt.dxf
ADDONS/AddOnB/Case Plates/Panel-B+Kalt.stl
ADDONS/AddOnB/Case Plates/Panel-B+Powercon.dxf
ADDONS/AddOnB/Case Plates/Panel-B+Powercon.stl
ADDONS/AddOnC/Case Plates/Panel-C+12v.dxf
ADDONS/AddOnC/Case Plates/Panel-C+12v.stl
ADDONS/AddOnC/Case Plates/Panel-C+Kalt.dxf
ADDONS/AddOnC/Case Plates/Panel-C+Kalt.stl
ADDONS/AddOnC/Case Plates/Panel-C+Powercon.dxf
ADDONS/AddOnC/Case Plates/Panel-C+Powercon.stl
ADDONS/AddOnD/Case Plates/Panel-D+12v.dxf
ADDONS/AddOnD/Case Plates/Panel-D+12v.stl
ADDONS/AddOnD/Case Plates/Panel-D+Powercon.dxf
ADDONS/AddOnD/Case Plates/Panel-D+Powercon.stl

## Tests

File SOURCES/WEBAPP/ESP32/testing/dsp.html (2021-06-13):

Channel 1 | Input | HP | LShlv | PEQ | PEQ | PEQ | PEQ | PEQ | PEQ | PEQ | PEQ | PEQ | PEQ | HShlv | LP | Phase | Delay | Gain | OUT 1
Channel 2 | Input | HP | LShlv | PEQ | PEQ | PEQ | PEQ | PEQ | PEQ | PEQ | PEQ | PEQ | PEQ | HShlv | LP | Phase | Delay | Gain | OUT 2
Channel 3 | Input | HP | LShlv | PEQ | PEQ | PEQ | PEQ | PEQ | PEQ | PEQ | PEQ | PEQ | PEQ | HShlv | LP | Phase | Delay | Gain | OUT 3
Channel 4 | Input | HP | LShlv | PEQ | PEQ | PEQ | PEQ | PEQ | PEQ | PEQ | PEQ | PEQ | PEQ | HShlv | LP | Phase | Delay | Gain | OUT 4
Channel 5 | Input | HP | LShlv | PEQ | PEQ | PEQ | PEQ | PEQ | PEQ | PEQ | PEQ | PEQ | PEQ | HShlv | LP | Phase | Delay | Gain | OUT 5
Channel 6 | Input | HP | LShlv | PEQ | PEQ | PEQ | PEQ | PEQ | PEQ | PEQ | PEQ | PEQ | PEQ | HShlv | LP | Phase | Delay | Gain | OUT 6
Channel 7 | Input | HP | LShlv | PEQ | PEQ | PEQ | PEQ | PEQ | PEQ | PEQ | PEQ | PEQ | PEQ | HShlv | LP | Phase | Delay | Gain | OUT 7
Channel 8 | Input | HP | LShlv | PEQ | PEQ | PEQ | PEQ | PEQ | PEQ | PEQ | PEQ | PEQ | PEQ | HShlv | LP | Phase | Delay | Gain | OUT 8

×

Input

Send

×

High Pass
| Hz
Send

×

Low Shelving
| dB
| Hz
| S
Send

×

Parametric EQ
| dB
| Hz
| Q
Send

×

High Shelving
| dB
| Hz
| S
Send

×

Low Pass
| Hz
Send

×

Phase
| Hz
| Q
Invert
Send

×

Delay
| ms
Send

×

Gain
| dB
Send

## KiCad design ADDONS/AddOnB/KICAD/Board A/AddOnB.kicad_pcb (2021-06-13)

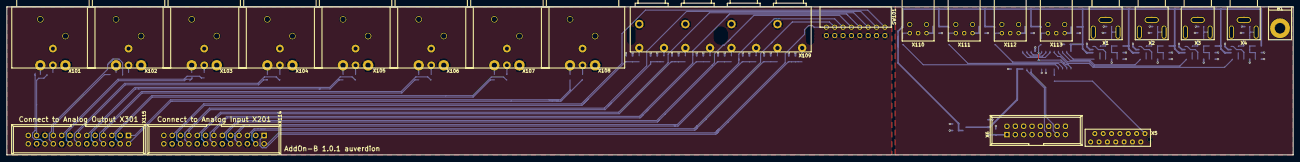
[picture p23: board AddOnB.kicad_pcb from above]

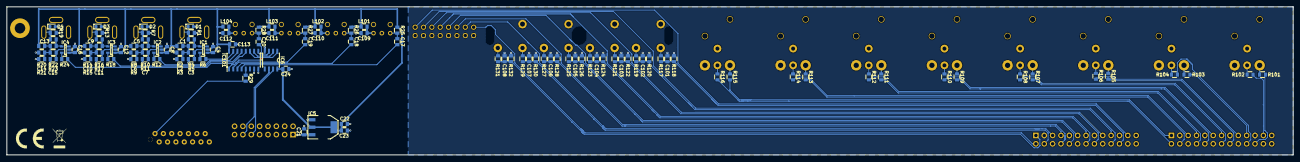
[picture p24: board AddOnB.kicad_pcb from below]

Board: 2 copper layers, 391.0 x 45.0 mm, 136 parts (113 on the bottom side), 102 nets.

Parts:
B1: Montagewinkel
C1, C2, C3, C4, C5, C6, C7, C8, C9, C10, C11, C12, C13, C14, C15, C16, C22, C24, C109, C110, C111, C112, C113: CAP_100n_50V_X7R_0805; C0805-X7R
C17, C18, C19, C20: CAP_10n0_50V_X7R_0805; C0805-X7R
C21, C23: CAP_10u0_25V_X5R_0805; C0805-X7R
C101, C102, C103, C104, C105, C106, C107, C108: CAP_100p_50V_C0G_NP0_0805; C0805-X7R
D1, D2, D3, D4: PESD0603-240; D_0603_1608Metric
IC1, IC2, IC3, IC4: FIN1002; SOT23-5
IC5: IC_NCP1117LPST33; SOT223
IC6: PCA9536D; SOIC8_3.9x4.9mm_Pitch1.27mm
IC101: 74HC251; SOIC-16_3.9x9.9mm_P1.27mm
L101, L102, L103, L104: 47u0; C0805-X7R
R1, R7, R13, R19: RES_91R0_1%_0.125W_Thick_0805; C0805-RES
R2, R8, R14, R20: RES_820R_1%_0.125W_Thick_0805; C0805-RES
R3, R4, R5, R9, R10, R11, R15, R16, R17, R21, R22, R23: RES_470R_1%_0.125W_Thick_0805; C0805-RES
R6, R12, R18, R24, R29: RES_33R0_1%_0.125W_Thick_0805; C0805-RES
R25, R26, R27, R28: RES_10K0_1%_0.125W_Thick_0805; C0805-RES
R101, R102, R103, R104, R105, R106, R107, R108, R109, R110, R111, R112, R113, R114, R115, R116: RES_68R0_1%_0.125W_Thin_0805; C0805-RES
R117, R119, R121, R123, R125, R127, R129, R131: RES_100R_1%_0.25W_Thin_0805; C0805-RES
R118, R120, R122, R124, R126, R128, R130, R132: RES_220K_1%_0.125W_Thick_0805; C0805-RES
SW101: SW_DIP_x08; KAS2108E
X1, X2, X3, X4: RCA; PJRAN1X1U01AUX
X5: MicroMatch14; MM-14G
X6: HDR_02x08; IDC2x8_Pitch2.54mm
X101, X102, X103, X104, X105, X106, X107, X108: XLR3; NC3MAH
X109: CONN_RCA_02x04; PJRAS4X2U01
X110, X111, X112, X113: PLR135_T10
X114, X115: CON_IDC26; IDC26

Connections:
+3V3: C4.1, C8.1, C12.1, C16.1, C22.1, C23.1, C24.2, C113.2, IC1.1, IC2.1, IC3.1, IC4.1, IC5.2, IC5.4, IC6.8, IC101.16, L101.1, L102.1, L103.1, L104.1, R2.1, R8.1, R14.1, R20.1, R25.2, R26.2, R27.2, R28.2
/AIN1+: C101.1, R117.2, R118.2, X114.22
/AIN1-: SW101.1, X114.23
/AIN2+: C102.1, R119.2, R120.2, X114.19
/AIN2-: SW101.2, X114.20
/AIN3+: C103.1, R121.2, R122.2, X114.16
/AIN3-: SW101.3, X114.17
/AIN4+: C104.1, R123.2, R124.2, X114.13
/AIN4-: SW101.4, X114.14
/AIN5+: C105.1, R125.2, R126.2, X114.10
/AIN5-: SW101.5, X114.11
/AIN6+: C106.1, R127.2, R128.2, X114.7
/AIN6-: SW101.6, X114.8
/AIN7+: C107.1, R129.2, R130.2, X114.4
/AIN7-: SW101.7, X114.5
/AIN8+: C108.1, R131.2, R132.2, X114.1
/AIN8-: SW101.8, X114.2
/AOUT1+: R101.1, X115.22
/AOUT1-: R102.1, X115.23
/AOUT2+: R103.1, X115.19
/AOUT2-: R104.1, X115.20
/AOUT3+: R105.1, X115.16
/AOUT3-: R106.1, X115.17
/AOUT4+: R107.1, X115.13
/AOUT4-: R108.1, X115.14
/AOUT5+: R109.1, X115.10
/AOUT5-: R110.1, X115.11
/AOUT6+: R111.1, X115.7
/AOUT6-: R112.1, X115.8
/AOUT7+: R113.1, X115.4
/AOUT7-: R114.1, X115.5
/AOUT8+: R115.1, X115.1
/AOUT8-: R116.1, X115.2
/SCL: IC6.6, X6.13
/SDA: IC6.7, X6.11
/SPDIF_RX: R29.2, X5.1
GND: C2.2, C3.2, C4.2, C6.2, C7.2, C8.2, C10.2, C11.2, C12.2, C14.2, C15.2, C16.2, C21.2, C22.2, C23.2, C24.1, C101.2, C102.2, C103.2, C104.2, C105.2, C106.2, C107.2, C108.2, C109.2, C110.2, C111.2, C112.2, C113.1, D1.2, D2.2, D3.2, D4.2, IC1.2, IC2.2, IC3.2, IC4.2, IC5.1, IC6.4, IC101.7, IC101.8, R1.1, R3.1, R7.1, R9.1, R13.1, R15.1, R19.1, R21.1, R118.1, R120.1, R122.1, R124.1, R126.1, R128.1, R130.1, R132.1, SW101.9, SW101.10, SW101.11, SW101.12, SW101.13, SW101.14, SW101.15, SW101.16, X1.2, X2.2, X3.2, X4.2, X5.2, X5.4, X5.6, X5.8, X5.10, X5.12, X6.2, X6.4, X6.6, X6.8, X6.10, X6.12, X6.14, X6.16, X101.1, X102.1, X103.1, X104.1, X105.1, X106.1, X107.1, X108.1, X109.3A, X109.3B, X109.3C, X109.3D, X110.2, X111.2, X112.2, X113.2, X114.3, X114.6, X114.9, X114.12, X114.15, X114.18, X114.21, X114.24, X115.3, X115.6, X115.9, X115.12, X115.15, X115.18, X115.21, X115.24
unnamed: C1.1, D1.1, R1.2, X1.1
unnamed: C1.2, IC1.4, R4.2
unnamed: C2.1, R2.2, R3.2, R4.1, R5.1
unnamed: C3.1, IC1.3, R5.2
unnamed: C5.1, D2.1, R7.2, X2.1
unnamed: C5.2, IC2.4, R10.2
unnamed: C6.1, R8.2, R9.2, R10.1, R11.1
unnamed: C7.1, IC2.3, R11.2
unnamed: C9.1, D3.1, R13.2, X3.1
unnamed: C9.2, IC3.4, R16.2
unnamed: C10.1, R14.2, R15.2, R16.1, R17.1
unnamed: C11.1, IC3.3, R17.2
unnamed: C13.1, D4.1, R19.2, X4.1
unnamed: C13.2, IC4.4, R22.2
unnamed: C14.1, R20.2, R21.2, R22.1, R23.1
unnamed: C15.1, IC4.3, R23.2
unnamed: C17.1, R25.1, X110.3
unnamed: C17.2, IC101.4
unnamed: C18.1, R26.1, X111.3
unnamed: C18.2, IC101.3
unnamed: C19.1, R27.1, X112.3
unnamed: C19.2, IC101.2
unnamed: C20.1, R28.1, X113.3
unnamed: C20.2, IC101.1
unnamed: C109.1, L101.2, X110.1
unnamed: C110.1, L102.2, X111.1
unnamed: C111.1, L103.2, X112.1
unnamed: C112.1, L104.2, X113.1
unnamed: IC1.5, R6.1
unnamed: IC2.5, R12.1
unnamed: IC3.5, R18.1
unnamed: IC4.5, R24.1
unnamed: IC101.5, R29.1
unnamed: IC6.3, IC101.9
unnamed: IC6.2, IC101.10
unnamed: IC6.1, IC101.11
unnamed: IC101.12, R24.2
unnamed: IC101.13, R18.2
unnamed: IC101.14, R12.2
unnamed: IC101.15, R6.2
unnamed: R101.2, X101.2
unnamed: R102.2, X101.3
unnamed: R103.2, X102.2
unnamed: R104.2, X102.3
unnamed: R105.2, X103.2
unnamed: R106.2, X103.3
unnamed: R107.2, X104.2
unnamed: R108.2, X104.3
unnamed: R109.2, X105.2
unnamed: R110.2, X105.3
unnamed: R111.2, X106.2
unnamed: R112.2, X106.3
unnamed: R113.2, X107.2
unnamed: R114.2, X107.3
unnamed: R115.2, X108.2
unnamed: R116.2, X108.3
unnamed: R117.1, X109.2A
unnamed: R119.1, X109.1A
unnamed: R121.1, X109.2B
unnamed: R123.1, X109.1B
unnamed: R125.1, X109.2C
unnamed: R127.1, X109.1C
unnamed: R129.1, X109.2D
unnamed: R131.1, X109.1D
VPP: C21.1, IC5.3, X6.1

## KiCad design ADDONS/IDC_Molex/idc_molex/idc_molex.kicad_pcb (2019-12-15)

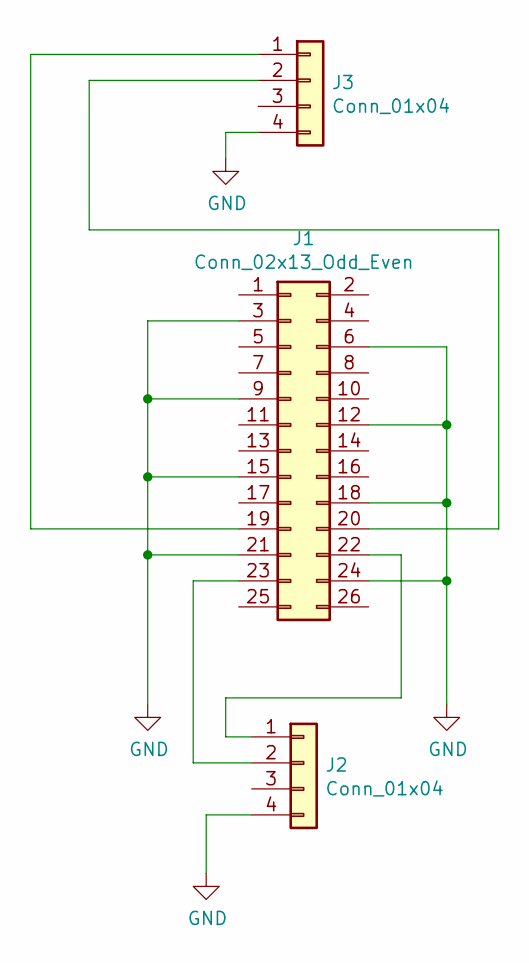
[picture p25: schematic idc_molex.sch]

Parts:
J1: Conn_02x13_Odd_Even; PinSocket_2x13_P2.54mm_Vertical
J2, J3: Conn_01x04; Molex_Micro-Fit_3.0_43045-0400_2x02_P3.00mm_Horizontal

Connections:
GND: J1.3, J1.6, J1.9, J1.12, J1.15, J1.18, J1.21, J1.24, J2.4, J3.4
unnamed: J1.19, J3.1
unnamed: J1.20, J3.2
unnamed: J1.22, J2.1
unnamed: J1.23, J2.2

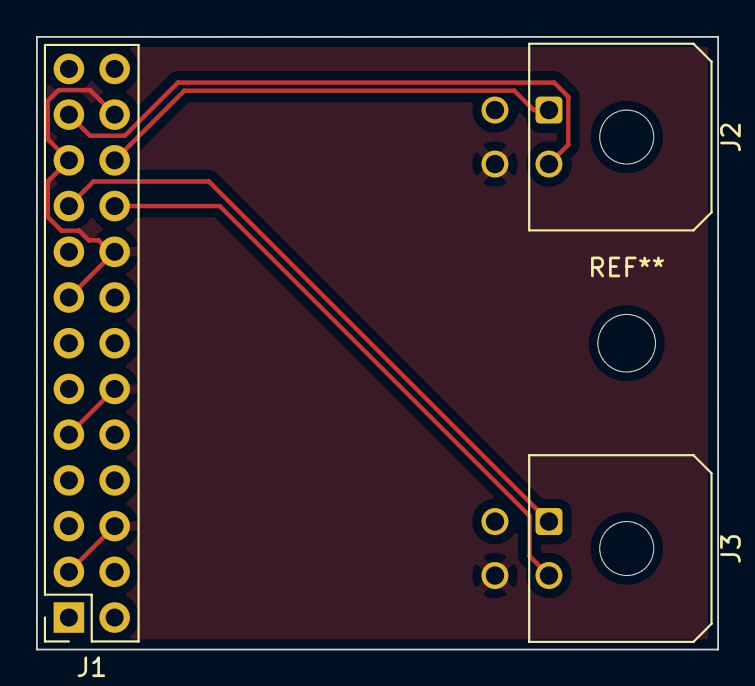
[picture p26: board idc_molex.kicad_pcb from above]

Board: 2 copper layers, 37.8 x 34.0 mm, 3 parts (0 on the bottom side), 5 nets.

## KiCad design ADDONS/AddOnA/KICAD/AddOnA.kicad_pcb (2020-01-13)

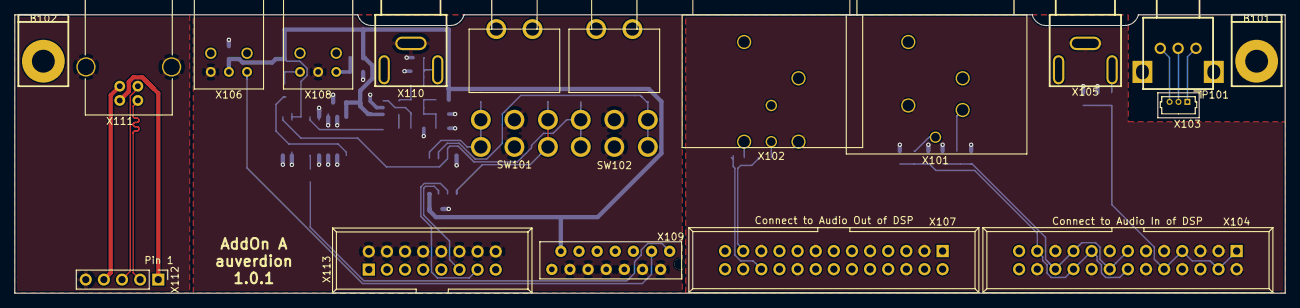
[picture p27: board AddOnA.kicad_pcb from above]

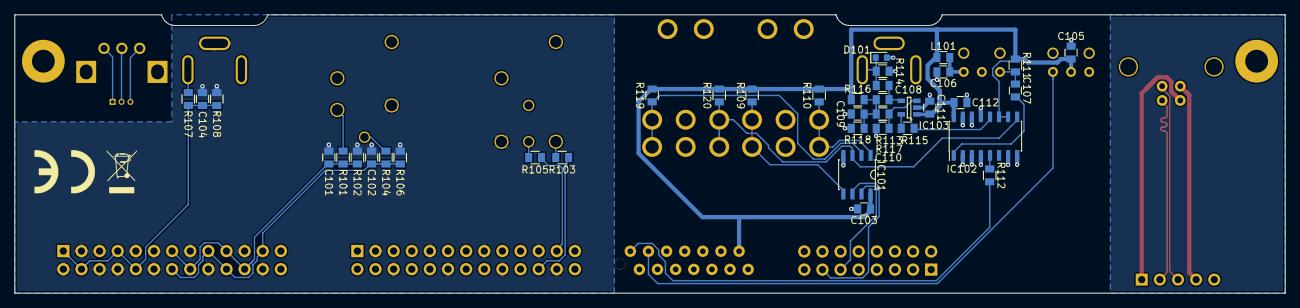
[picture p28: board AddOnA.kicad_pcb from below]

Board: 2 copper layers, 178.0 x 39.0 mm, 55 parts (37 on the bottom side), 38 nets.

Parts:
B101, B102: Montagewinkel
C101, C102, C104: CAP_100p_50V_C0G_NP0_0805; C0805-X7R
C103, C105, C106, C108, C109, C110, C111, C112: CAP_100n_50V_X7R_0805; C0805-X7R
C107: CAP_10n0_50V_X7R_0805; C0805-X7R
D101: PESD0603-240; D_0603_1608Metric
IC101: PCA9536D; SOIC8_3.9x4.9mm_Pitch1.27mm
IC102: 74HC251; SOIC-16_3.9x9.9mm_P1.27mm
IC103: FIN1002; SOT23-5
L101: 47u0; C0805-X7R
P101: 10K0; RK09K1110-20
R101, R104, R107: RES_100R_1%_0.25W_Thin_0805; C0805-RES
R102, R106: RES_100K_1%_0.125W_Thick_0805; C0805-RES
R103, R105: RES_68R0_1%_0.125W_Thin_0805; C0805-RES
R108: RES_220K_1%_0.125W_Thick_0805; C0805-RES
R109, R110, R119, R120: RES_47K0_1%_0.125W_Thick_0805; C0805-RES
R111: RES_10K0_1%_0.125W_Thick_0805; C0805-RES
R112, R115: RES_33R0_1%_0.125W_Thick_0805; C0805-RES
R113, R117, R118: RES_470R_1%_0.125W_Thick_0805; C0805-RES
R114: RES_91R0_1%_0.125W_Thick_0805; C0805-RES
R116: RES_820R_1%_0.125W_Thick_0805; C0805-RES
SW101, SW102: Switch_DPDT; GEMINI_A
X101: XLR3; NC3FAH
X102: XLR3; NC3MAH
X103: Conn_01x03; Molex_PicoBlade_530470310
X104, X107: CON_IDC26; IDC26
X105, X110: RCA; PJRAN1X1U01AUX
X106: PLT133_T10W
X108: PLR135_T10
X109: MicroMatch14; MM-14G
X111: CON_USB_B; USB_B
X112: HDR_01x05; PinHeader_1x05_P2.54mm_Vertical
X113: HDR_02x08; IDC2x8_Pitch2.54mm

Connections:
+3V3: C103.2, C105.2, C111.1, C112.2, IC101.8, IC102.10, IC102.11, IC102.16, IC103.1, L101.1, R109.2, R110.2, R111.2, R116.1, R119.2, R120.2, X106.2, X109.13
/AIN1+: C101.1, R101.2, R102.2, X104.13, X104.16, X104.19, X104.22
/AIN1-: C102.1, R104.2, R106.2, X104.14, X104.17, X104.20, X104.23
/AIN5+: C104.1, R107.2, R108.2, X104.1, X104.4, X104.7, X104.10
/AOUT1+: R103.1, X107.22
/AOUT1-: R105.1, X107.23
/D+: X111.3, X112.3
/D-: X111.2, X112.2
/DIGSEL:0: IC101.3, IC102.9, R120.1, SW102.3, SW102.6
/DIGSEL:1: IC101.2, R119.1, SW102.1, SW102.4
/DIG_LEFT: IC101.5, R109.1, SW101.1, SW101.4
/DIG_RIGHT: IC101.1, R110.1, SW101.3, SW101.6
/SCL: IC101.6, X113.13
/SDA: IC101.7, X113.11
/SPDIF_RX: R112.2, X109.1
/SPDIF_TX: X106.1, X109.3
GND: C101.2, C102.2, C103.1, C104.2, C105.1, C106.2, C109.2, C110.2, C111.2, C112.1, D101.2, IC101.4, IC102.2, IC102.3, IC102.4, IC102.7, IC102.8, IC102.13, IC102.14, IC102.15, IC103.2, R102.1, R106.1, R108.1, R114.1, R118.1, SW101.2, SW101.5, SW102.2, SW102.5, X101.1, X102.1, X104.2, X104.3, X104.5, X104.6, X104.8, X104.9, X104.11, X104.12, X104.15, X104.18, X104.21, X104.24, X105.2, X106.3, X107.3, X107.6, X107.9, X107.12, X107.15, X107.18, X107.21, X107.24, X108.2, X109.2, X109.4, X109.6, X109.8, X109.10, X109.12, X110.2, X113.2, X113.4, X113.6, X113.8, X113.10, X113.12, X113.14, X113.16
unnamed: C106.1, L101.2, X108.1
unnamed: C107.1, R111.1, X108.3
unnamed: C107.2, IC102.1
unnamed: C108.1, D101.1, R114.2, X110.1
unnamed: C108.2, IC103.4, R113.2
unnamed: C109.1, R113.1, R116.2, R117.1, R118.2
unnamed: C110.1, IC103.3, R117.2
unnamed: IC102.5, R112.1
unnamed: IC102.12, R115.2
unnamed: IC103.5, R115.1
unnamed: P101.1, X103.1
unnamed: P101.2, X103.2
unnamed: P101.3, X103.3
unnamed: R101.1, X101.2
unnamed: R103.2, X102.2
unnamed: R104.1, X101.3
unnamed: R105.2, X102.3
unnamed: R107.1, X105.1
unnamed: X111.1, X112.1
unnamed: X111.4, X112.4
unnamed: X111.5, X112.5

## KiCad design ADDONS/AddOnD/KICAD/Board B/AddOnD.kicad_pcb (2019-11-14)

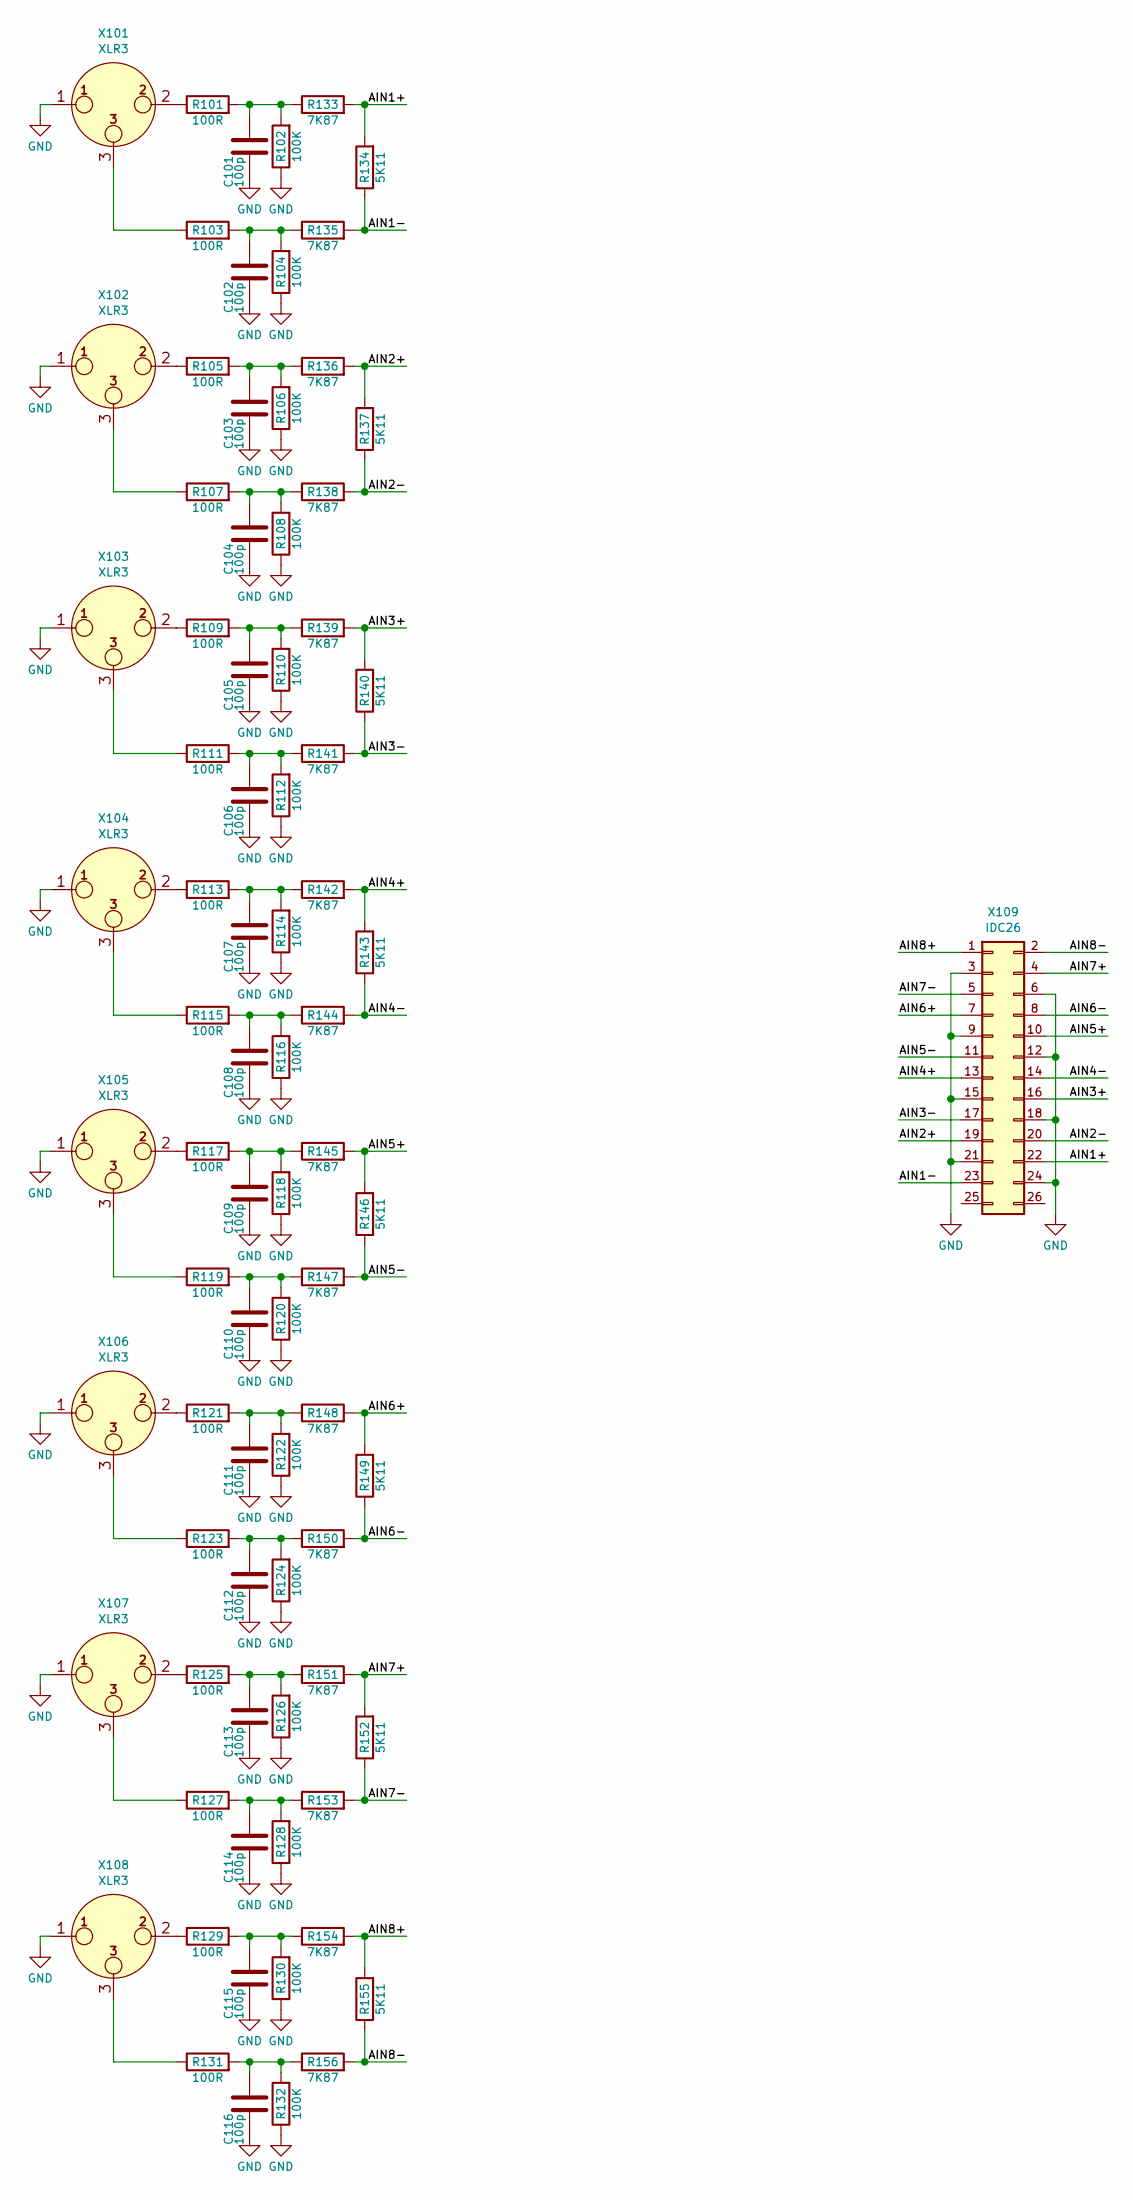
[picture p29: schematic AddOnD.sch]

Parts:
C101, C102, C103, C104, C105, C106, C107, C108, C109, C110, C111, C112, C113, C114, C115, C116: CAP_100p_50V_C0G_NP0_0805; C0805-X7R; digikey 399-1122-1-ND
R101, R103, R105, R107, R109, R111, R113, R115, R117, R119, R121, R123, R125, R127, R129, R131: RES_100R_1%_0.25W_Thin_0805; C0805-RES; digikey RNCP0805FTD100RCT-ND
R102, R104, R106, R108, R110, R112, R114, R116, R118, R120, R122, R124, R126, R128, R130, R132: RES_100K_1%_0.125W_Thick_0805; C0805-RES; digikey 311-100KCRCT-ND
R133, R135, R136, R138, R139, R141, R142, R144, R145, R147, R148, R150, R151, R153, R154, R156: RES_7K87_0.5%_0.100W_Thin_0805; C0805-RES; digikey RR12P7.87KDCT-ND
R134, R137, R140, R143, R146, R149, R152, R155: RES_5K11_0.5%_0.100W_Thin_0805; C0805-RES; digikey RR12P5.11KDCT-ND
X101, X102, X103, X104, X105, X106, X107, X108: XLR3; NC3FAH
X109: CON_IDC26; IDC26; digikey 377-2269-ND

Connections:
/AIN1+: R133.2, R134.2, X109.22
/AIN1-: R134.1, R135.2, X109.23
/AIN2+: R136.2, R137.2, X109.19
/AIN2-: R137.1, R138.2, X109.20
/AIN3+: R139.2, R140.2, X109.16
/AIN3-: R140.1, R141.2, X109.17
/AIN4+: R142.2, R143.2, X109.13
/AIN4-: R143.1, R144.2, X109.14
/AIN5+: R145.2, R146.2, X109.10
/AIN5-: R146.1, R147.2, X109.11
/AIN6+: R148.2, R149.2, X109.7
/AIN6-: R149.1, R150.2, X109.8
/AIN7+: R151.2, R152.2, X109.4
/AIN7-: R152.1, R153.2, X109.5
/AIN8+: R154.2, R155.2, X109.1
/AIN8-: R155.1, R156.2, X109.2
GND: C101.2, C102.2, C103.2, C104.2, C105.2, C106.2, C107.2, C108.2, C109.2, C110.2, C111.2, C112.2, C113.2, C114.2, C115.2, C116.2, R102.1, R104.1, R106.1, R108.1, R110.1, R112.1, R114.1, R116.1, R118.1, R120.1, R122.1, R124.1, R126.1, R128.1, R130.1, R132.1, X101.1, X102.1, X103.1, X104.1, X105.1, X106.1, X107.1, X108.1, X109.3, X109.6, X109.9, X109.12, X109.15, X109.18, X109.21, X109.24
unnamed: C101.1, R101.2, R102.2, R133.1
unnamed: C102.1, R103.2, R104.2, R135.1
unnamed: C103.1, R105.2, R106.2, R136.1
unnamed: C104.1, R107.2, R108.2, R138.1
unnamed: C105.1, R109.2, R110.2, R139.1
unnamed: C106.1, R111.2, R112.2, R141.1
unnamed: C107.1, R113.2, R114.2, R142.1
unnamed: C108.1, R115.2, R116.2, R144.1
unnamed: C109.1, R117.2, R118.2, R145.1
unnamed: C110.1, R119.2, R120.2, R147.1
unnamed: C111.1, R121.2, R122.2, R148.1
unnamed: C112.1, R123.2, R124.2, R150.1
unnamed: C113.1, R125.2, R126.2, R151.1
unnamed: C114.1, R127.2, R128.2, R153.1
unnamed: C115.1, R129.2, R130.2, R154.1
unnamed: C116.1, R131.2, R132.2, R156.1
unnamed: R101.1, X101.2
unnamed: R103.1, X101.3
unnamed: R105.1, X102.2
unnamed: R107.1, X102.3
unnamed: R109.1, X103.2
unnamed: R111.1, X103.3
unnamed: R113.1, X104.2
unnamed: R115.1, X104.3
unnamed: R117.1, X105.2
unnamed: R119.1, X105.3
unnamed: R121.1, X106.2
unnamed: R123.1, X106.3
unnamed: R125.1, X107.2
unnamed: R127.1, X107.3
unnamed: R129.1, X108.2
unnamed: R131.1, X108.3

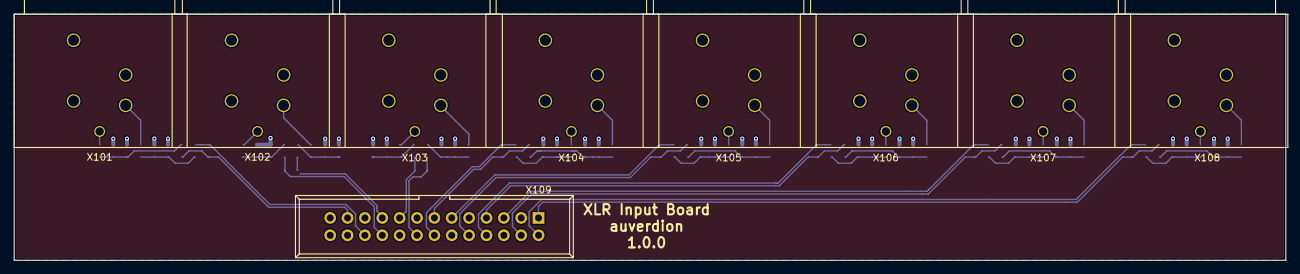
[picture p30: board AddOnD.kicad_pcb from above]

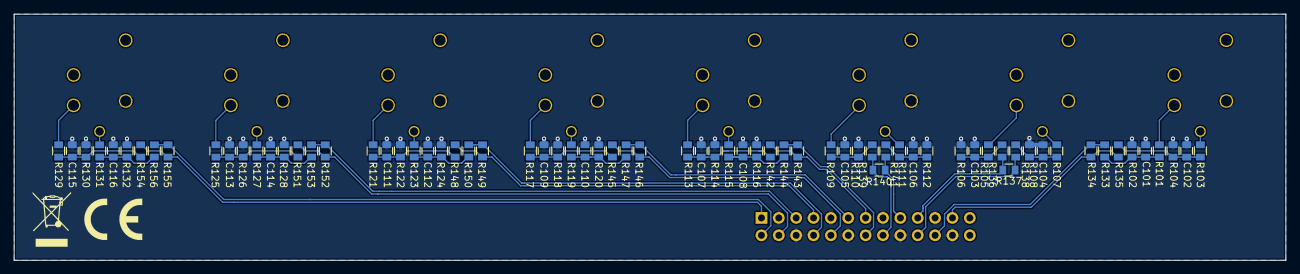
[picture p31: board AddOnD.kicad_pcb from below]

Board: 2 copper layers, 186.0 x 36.0 mm, 81 parts (72 on the bottom side), 49 nets.

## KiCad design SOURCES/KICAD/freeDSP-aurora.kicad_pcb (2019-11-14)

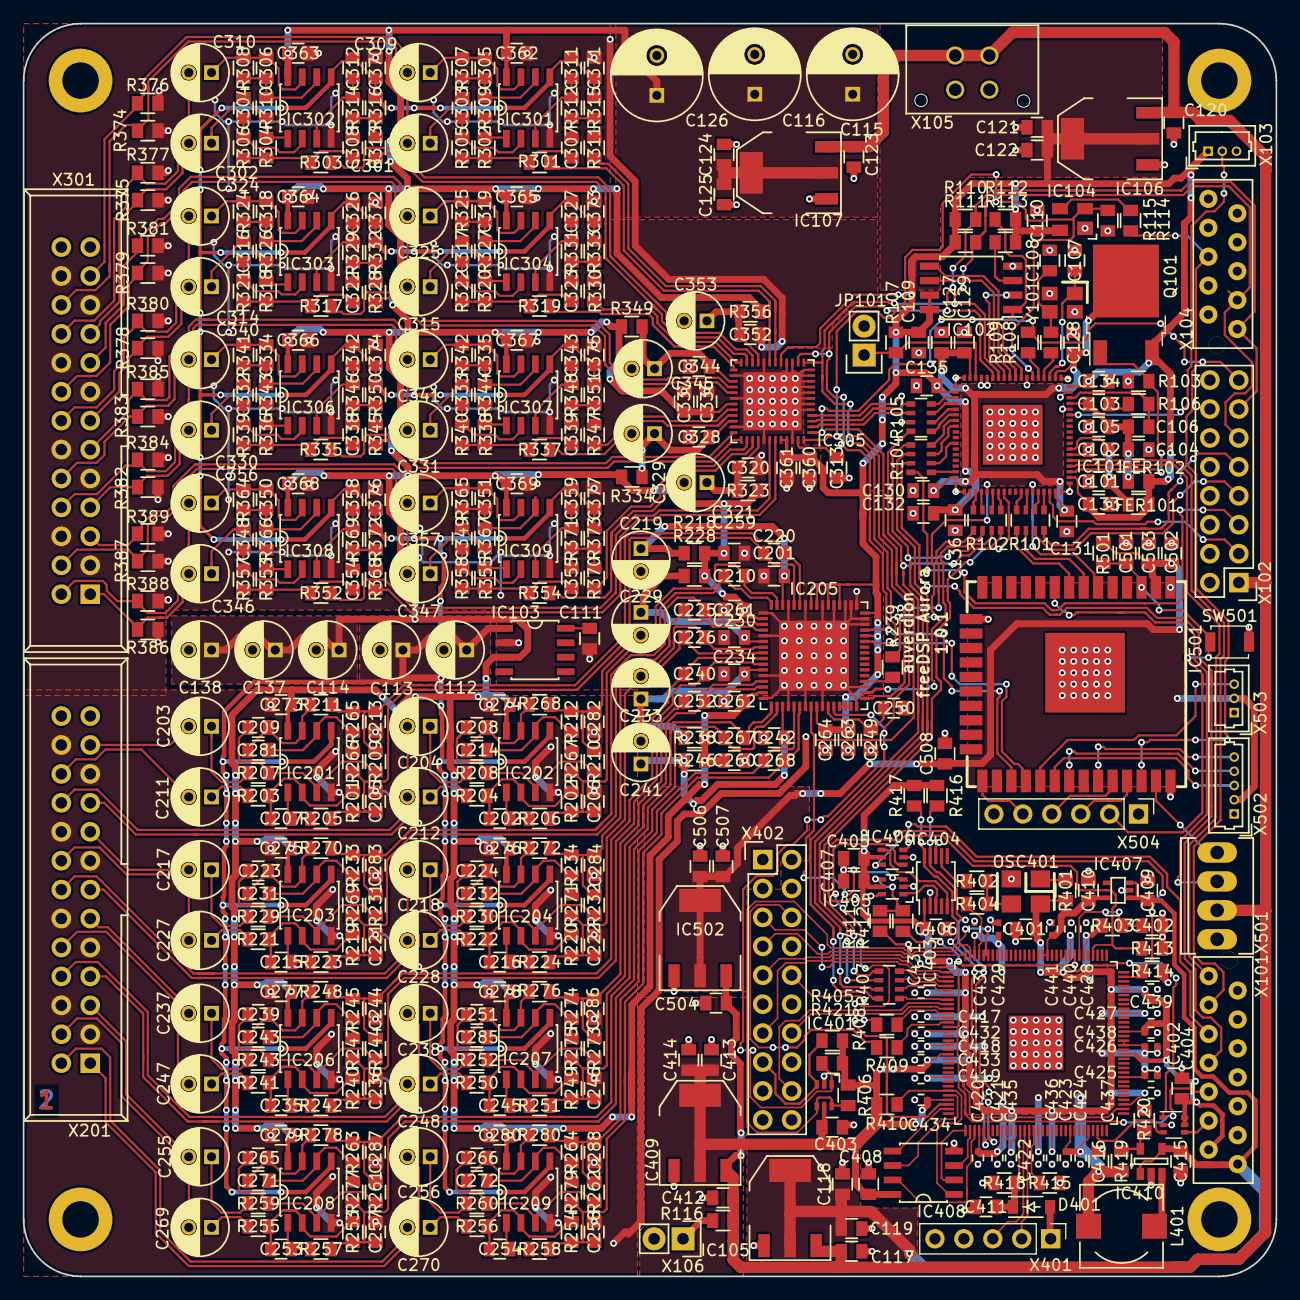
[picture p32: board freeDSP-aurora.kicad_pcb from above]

Board: 2 copper layers, 110.0 x 110.0 mm, 506 parts (0 on the bottom side), 316 nets.

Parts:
B101, B102, B103, B104: TEST_1P; MountingHole_3.2mm_M3_DIN965_Pad
C101, C104, C111, C117, C119, C120, C122, C123, C125, C127, C132, C259, C260, C337, C360, C409, C410, C412, C414, C415, C502, C507, C508: CAP_10u0_25V_X5R_0805; C0805-X7R
C102, C105, C109, C110, C118, C121, C124, C128, C129, C130, C131, C133, C134, C135, C136, C220, C230, C234, C242, C249, C261, C262, C264, C273, C274, C275, C276, C277, C278, C279, C280, C320, C328, C336, C344, C352, C361, C362, C363, C364, C365, C366, C367, C368, C369, C370, C371, C372, C373, C374, C375, C376, C377, C402, C403, C404, C405, C406, C407, C408, C411, C413, C501, C503, C506: CAP_100n_50V_X7R_0805; C0805-X7R
C103: CAP_5n60_50V_X7R_0805; C0805-X7R
C106: CAP_150p_50V_C0G_0805; C0805-X7R
C107, C108: CAP_22p0_50V_C0G_NP0_0805; C0805-X7R
C112, C113, C114, C137, C138, C203, C204, C211, C212, C217, C218, C219, C227, C228, C229, C233, C237, C238, C241, C247, C248, C255, C256, C269, C270, C301, C302, C309, C310, C314, C315, C321, C324, C325, C329, C330, C331, C340, C341, C345, C346, C347, C353, C356, C357: CAP_100u_20%_25V_ALUM_RADIAL; RD2_D5_L11
C115, C116, C126: 330u_20%_25V_ALUM_RADIAL; RD3.5_D8_L14
C201, C210, C225, C226, C240, C252, C267, C268: CAP_1n00_5%_50V_PPS_0805; C0805-X7R
C202, C207, C208, C209, C215, C216, C223, C224, C235, C239, C245, C251, C253, C254, C265, C266: CAP_220p_2%_50V_PPS_0805; C0805-X7R
C205, C206, C213, C214, C221, C222, C231, C232, C236, C243, C244, C246, C257, C258, C271, C272, C281, C282, C283, C284, C285, C286, C287, C288: CAP_100p_50V_C0G_NP0_0805; C0805-X7R
C250: CAP_4u70_25V_X5R_0805; C0805-X7R
C263, C401: CAP_10n0_50V_X7R_0805; C0805-X7R
C303, C304, C311, C312, C316, C317, C326, C327, C332, C333, C342, C343, C348, C349, C358, C359: CAP_470p_2%_50V_PPS_0805; C0805-X7R
C305, C306, C318, C319, C334, C335, C350, C351: CAP_27p0_50V_C0G_NP0_0805; C0805-X7R
C307, C308, C322, C323, C338, C339, C354, C355: CAP_3n90_5%_16V_PPS_0805; C0805-X7R
C313: CAP_1u00_16V_X7R_0805; C0805-X7R
C416, C504: CAP_22u0_10V_X5R_0805; C0805-X7R
C417, C418, C419, C420, C421, C422, C423, C424, C425, C426, C427, C428, C429, C430, C431, C432, C433, C434, C435, C436, C437, C438, C439, C440, C441: CAP_100n_10V_X7R_0402; C_0402
D401: DIO_MBR120VLSFT; SOD123
FER101, FER102: FER_600R_600MA_0805; C0805-RES
IC101: IC_ADAU1452; QFP72_10x10_EP_Handsoldering
IC102: IC_25AA1024; SOIJ8_5.3x5.3mm_P1.27mm
IC103: IC_TLE2426ID; SOIC8_3.9x4.9mm_Pitch1.27mm
IC104: IC_ADM811TARTZ; SOT143
IC105, IC107: IC_LM1117MP-5.0; SOT223
IC106, IC409, IC502: IC_NCP1117LPST33; SOT223
IC201, IC202, IC203, IC204, IC206, IC207, IC208, IC209, IC301, IC302, IC303, IC304, IC306, IC307, IC308, IC309: IC_OPA1652AIDR; SOIC8_3.9x4.9mm_Pitch1.27mm
IC205: IC_AK5558VN; QFN64_9x9mm_Pitch0.5mm_EP_Handsoldering
IC305: IC_AK4458VN; QFN48_7x7mm_Pitch0.5mm_EP_Handsoldering
IC401: IC_NC7WZ07; SC-70-6
IC402: NC7SZ175; SOT-363_SC-70-6
IC403: IC_XE216-512-TQ128; TQFP-128_14x14mm_Pitch0.4mm_EP_Handsoldering
IC404: IC_CS2100CP; MSOP-10_3x3mm_Pitch0.5mm
IC405, IC406: NC7SZ157; SC-70-6
IC407: TLV70025; SC70-5
IC408: IC_IS25LP080D; SOIC8_3.9x4.9mm_Pitch1.27mm
IC410: IC_TLV62565; SOT-23-5
IC501: ESP32-WROOM-32U
JP101: CON_JUMPER; HDR_01x02
L401: IND_2U20_30%_4A5; MCSDRH73B
OSC401: OSC_24M0; ASFL1
Q101: Q_STD2805; TO-252-2
R101, R102, R104, R105, R407: 33R0_5%_4x0603; R_Array_Convex_4x0603
R103, R114, R410: RES_1K00_1%_0.125W_Thick_0805; C0805-RES
R106: RES_4K32_1%_0.125W_Thick_0805; C0805-RES
R107, R112, R113, R401, R405, R406, R413, R414, R421, R501: RES_10K0_1%_0.125W_Thick_0805; C0805-RES
R108: RES_100R_1%_0.125W_Thick_0805; C0805-RES
R109, R239, R402, R404, R408, R409, R411, R412: RES_33R0_1%_0.125W_Thick_0805; C0805-RES
R110, R111, R416, R417: RES_2K00_1%_0.125W_Thick_0805; C0805-RES
R115, R374, R375, R376, R377, R378, R379, R380, R381, R382, R383, R384, R385, R386, R387, R388, R389, R418: RES_100K_1%_0.125W_Thick_0805; C0805-RES
R116: RES_560R_1%_0.125W_Thick_0805; C0805-RES
R201, R202, R209, R210, R219, R220, R231, R232, R240, R244, R249, R253, R254, R261, R262, R273: RES_6K80_0.5%_0.125W_Thin_0805; C0805-RES
R203, R204, R207, R208, R221, R222, R229, R230, R241, R243, R250, R252, R255, R256, R259, R260: RES_10K0_1%_0.25W_Thin_0805; C0805-RES
R205, R206, R211, R223, R224, R242, R248, R251, R257, R258, R268, R270, R272, R276, R278, R280: RES_10R0_1%_0.25W_Thin_0805; C0805-RES
R212, R233, R234, R245, R247, R263, R264, R265, R266, R267, R269, R271, R274, R275, R277, R279: RES_2K20_0.5%_0.125W_Thin_0805; C0805-RES
R218, R228, R238, R246, R323, R334, R349, R356: RES_20R0_1%_0.125W_Thick_0805; C0805-RES
R301, R303, R311, R313, R317, R319, R328, R330, R335, R337, R345, R347, R352, R354, R368, R370: RES_4K42_0.5%_0.1W_Thin_0805; C0805-RES
R302, R304, R315, R316, R318, R320, R332, R333, R336, R338, R350, R351, R353, R355, R372, R373: RES_3K40_0.5%_0.1W_Thin_0805; C0805-RES
R305, R306, R312, R314, R321, R322, R329, R331, R339, R340, R346, R348, R357, R358, R369, R371: RES_150R_1%_0.25W_Thin_0805; C0805-RES
R307, R308, R309, R310, R324, R325, R326, R327, R341, R342, R343, R344, R364, R365, R366, R367: RES_4K70_1%_0.125W_Thin_0805; C0805-RES
R403: RES_4R70_1%_0.125W_Thick_0805; C0805-RES
R415: RES_43R2_1%_0.125W_Thick_0805; C0805-RES
R419: RES_80K6_1%_0.125W_Thick_0805; C0805-RES
R420: RES_120K_1%_0.125W_Thick_0805; C0805-RES
SW501: SW_Push; SW_SPST_B3U-1000P
X101: MicroMatch14; MM-14G
X102: HDR_02x08
X103, X503: Conn_01x03; Molex_PicoBlade_530470310
X104: CON_MicroMatch-10G; MM-10G
X105: CON_MicroFit3_02x02; Microfit3_43045-0428
X106: Conn_01x02; HDR_01x02
X201, X301: CON_IDC26; IDC26
X401: HDR_01x05; PinHeader_1x05_P2.54mm_Vertical
X402: CON_HDR_02x10; HDR_02x10
X501: Conn_01x04; Molex_KK254_0022032041
X502: Conn_01x05; Molex_PicoBlade_530470510
X504: HDR_01x06; PinHeader_1x06_P2.54mm_Vertical
Y101: 24M576; Crystal-3.2x2.5

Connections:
+1V0: C416.1, C417.1, C418.1, C419.1, C420.1, C421.1, C422.1, C423.1, C424.1, C425.1, C426.1, C427.1, C428.1, C429.1, C430.1, IC403.11, IC403.16, IC403.17, IC403.24, IC403.36, IC403.41, IC403.49, IC403.56, IC403.60, IC403.73, IC403.80, IC403.81, IC403.87, IC403.101, IC403.102, IC403.120, IC403.126, L401.2, R403.2, R419.1
+2V5: C410.2, C441.1, IC403.110, IC403.111, IC407.5
+3V3: C109.1, C110.1, C121.1, C122.1, C132.1, C133.1, C134.1, C135.1, C136.1, C263.1, C264.1, C360.1, C361.1, FER101.1, FER102.1, IC101.2, IC101.18, IC101.38, IC101.56, IC102.7, IC102.8, IC104.4, IC106.2, IC106.4, IC205.25, IC205.29, IC205.30, IC205.31, IC205.44, IC205.48, IC205.52, IC205.54, IC205.56, IC205.57, IC305.17, IC305.44, IC305.45, Q101.3, R103.1, R107.1, R110.1, R111.1, R112.1, R113.1, X103.1
+5V: C118.1, C119.1, C409.2, C415.2, IC105.2, IC105.4, IC407.1, IC407.3, IC410.1, IC410.4, X101.14
+5VA: C114.1, C115.1, C116.1, C124.1, C125.1, C126.1, C137.1, C138.1, C259.1, C260.1, C261.1, C262.1, C273.1, C274.1, C275.1, C276.1, C277.1, C278.1, C279.1, C280.1, C336.1, C337.1, C362.1, C363.1, C364.1, C365.1, C366.1, C367.1, C368.1, C369.1, IC103.3, IC107.2, IC107.4, IC201.8, IC202.8, IC203.8, IC204.8, IC205.2, IC205.15, IC206.8, IC207.8, IC208.8, IC209.8, IC301.8, IC302.8, IC303.8, IC304.8, IC305.31, IC306.8, IC307.8, IC308.8, IC309.8, R218.2, R228.2, R238.2, R246.2, R323.1, R334.1, R349.1, R356.1
+12V: C117.1, C120.1, C123.1, C412.2, C504.1, IC105.3, IC106.3, IC107.3, IC409.3, IC502.3, R116.1, X102.1, X105.1, X105.2, X501.2
/AD-Wandler/ADC1+: C201.2, C213.2, IC205.59, R209.1, R211.1, R265.1
/AD-Wandler/ADC1-: C201.1, C205.1, IC205.60, R201.1, R205.1, R266.2
/AD-Wandler/ADC2+: C210.2, C282.2, IC205.63, R210.1, R212.1, R268.1
/AD-Wandler/ADC2-: C206.1, C210.1, IC205.64, R202.1, R206.1, R267.2
/AD-Wandler/ADC3+: C225.2, C283.2, IC205.3, R231.1, R233.1, R270.1
/AD-Wandler/ADC3-: C221.1, C225.1, IC205.4, R219.1, R223.1, R269.2
/AD-Wandler/ADC4+: C226.2, C284.2, IC205.7, R232.1, R234.1, R272.1
/AD-Wandler/ADC4-: C222.1, C226.1, IC205.8, R220.1, R224.1, R271.2
/AD-Wandler/ADC5+: C240.2, C244.2, IC205.9, R244.1, R245.1, R248.1
/AD-Wandler/ADC5-: C236.1, C240.1, IC205.10, R240.1, R242.1, R247.2
/AD-Wandler/ADC6+: C252.2, C286.2, IC205.13, R273.1, R274.1, R276.1
/AD-Wandler/ADC6-: C246.1, C252.1, IC205.14, R249.1, R251.1, R275.2
/AD-Wandler/ADC7+: C267.2, C287.2, IC205.17, R261.1, R263.1, R278.1
/AD-Wandler/ADC7-: C257.1, C267.1, IC205.18, R253.1, R257.1, R277.2
/AD-Wandler/ADC8+: C268.2, C288.2, IC205.21, R262.1, R264.1, R280.1
/AD-Wandler/ADC8-: C258.1, C268.1, IC205.22, R254.1, R258.1, R279.2
/AD-Wandler/AIN1+: C211.2, X201.22
/AD-Wandler/AIN1-: C203.2, X201.23
/AD-Wandler/AIN2+: C204.2, X201.19
/AD-Wandler/AIN2-: C212.2, X201.20
/AD-Wandler/AIN3+: C227.2, X201.16
/AD-Wandler/AIN3-: C217.2, X201.17
/AD-Wandler/AIN4+: C218.2, X201.13
/AD-Wandler/AIN4-: C228.2, X201.14
/AD-Wandler/AIN5+: C247.2, X201.10
/AD-Wandler/AIN5-: C237.2, X201.11
/AD-Wandler/AIN6+: C238.2, X201.7
/AD-Wandler/AIN6-: C248.2, X201.8
/AD-Wandler/AIN7+: C269.2, X201.4
/AD-Wandler/AIN7-: C255.2, X201.5
/AD-Wandler/AIN8+: C256.2, X201.1
/AD-Wandler/AIN8-: C270.2, X201.2
/AUXADC5: IC101.13, X103.2
/BCLK:2: IC501.8, R101.5
/BCLK:3: R101.7, X102.7
/BCLK_ADC: IC205.33, R102.5
/BCLK_DAC: IC305.2, R105.6
/DA-Wandler/AOUT1+: C301.2, R374.2, X301.22
/DA-Wandler/AOUT1-: C309.2, R376.2, X301.23
/DA-Wandler/AOUT2+: C302.2, R375.2, X301.19
/DA-Wandler/AOUT2-: C310.2, R377.2, X301.20
/DA-Wandler/AOUT3+: C315.2, R379.2, X301.16
/DA-Wandler/AOUT3-: C325.2, R381.2, X301.17
/DA-Wandler/AOUT4+: C314.2, R378.2, X301.13
/DA-Wandler/AOUT4-: C324.2, R380.2, X301.14
/DA-Wandler/AOUT5+: C331.2, R383.2, X301.10
/DA-Wandler/AOUT5-: C341.2, R385.2, X301.11
/DA-Wandler/AOUT6+: C330.2, R382.2, X301.7
/DA-Wandler/AOUT6-: C340.2, R384.2, X301.8
/DA-Wandler/AOUT7+: C347.2, R387.2, X301.4
/DA-Wandler/AOUT7-: C357.2, R389.2, X301.5
/DA-Wandler/AOUT8+: C346.2, R386.2, X301.1
/DA-Wandler/AOUT8-: C356.2, R388.2, X301.2
/DA-Wandler/DAC1+: IC305.18, R311.2
/DA-Wandler/DAC1-: IC305.19, R301.2
/DA-Wandler/DAC2+: IC305.23, R313.2
/DA-Wandler/DAC2-: IC305.22, R303.2
/DA-Wandler/DAC3+: IC305.24, R330.2
/DA-Wandler/DAC3-: IC305.25, R319.2
/DA-Wandler/DAC4+: IC305.29, R328.2
/DA-Wandler/DAC4-: IC305.28, R317.2
/DA-Wandler/DAC5+: IC305.32, R347.2
/DA-Wandler/DAC5-: IC305.33, R337.2
/DA-Wandler/DAC6+: IC305.37, R345.2
/DA-Wandler/DAC6-: IC305.36, R335.2
/DA-Wandler/DAC7+: IC305.38, R370.2
/DA-Wandler/DAC7-: IC305.39, R354.2
/DA-Wandler/DAC8+: IC305.43, R368.2
/DA-Wandler/DAC8-: IC305.42, R352.2
/ESP32/EN: C501.2, IC501.3, R501.2, SW501.2, X504.2
/ESP32/FANCTRL: IC501.37, X501.4
/ESP32/IO0: IC501.25, X504.5
/ESP32/IRREMOTE: IC501.29, X503.3
/ESP32/PUSHSW: IC501.30, X502.3
/ESP32/ROTI: IC501.33, X502.5
/ESP32/ROTQ: IC501.31, X502.4
/ESP32/RXD: IC501.34, X504.4
/ESP32/SENSE: IC501.9, X501.3
/ESP32/TXD: IC501.35, X504.3
/LRCK:2: IC501.7, R101.6
/LRCK:3: R101.8, X102.9
/LRCK_ADC: IC205.34, R102.6
/LRCK_DAC: IC305.3, R105.5
/MCLK: IC205.24, IC305.1, IC405.3, R109.2, X102.15
/MDI:2: IC101.67, IC501.6
/MDI:3: IC101.70, X102.3
/MDO:3: R104.8, X102.5
/OPTICAL_RX: IC403.20, X101.9
/OPTICAL_TX: IC402.4, X101.11
/SCL: IC101.31, IC205.45, IC305.14, IC501.27, R110.2, X102.13, X104.1
/SDA: IC101.30, IC205.43, IC305.13, IC501.28, R111.2, X102.11, X104.3
/SPDIF_RX: IC101.4, X101.1
/SPDIF_TX: IC101.5, X101.3
/TDM_ADC: IC101.59, R239.1
/TDM_DAC: IC305.4, R105.7
/VGROUND: C112.1, C113.1, C311.2, C312.2, C326.2, C327.2, C342.2, C343.2, C358.2, C359.2, C370.1, C371.1, C372.1, C373.1, C374.1, C375.1, C376.1, C377.1, IC103.1, IC201.5, IC202.5, IC203.5, IC204.5, IC206.5, IC207.5, IC208.5, IC209.5, IC301.5, IC302.5, IC303.5, IC304.5, IC306.5, IC307.5, IC308.5, IC309.5, R315.2, R316.2, R332.2, R333.2, R350.2, R351.2, R372.2, R373.2
/WCLK_RX: IC406.3, X101.5
/WCLK_TX: R104.7, X101.7
/XMOS/24M: IC404.7, R402.1
/XMOS/CLK: IC403.125, R404.1
/XMOS/MCLK_DIO: IC402.1, R412.1
/XMOS/OPT_TX: IC402.3, IC403.62
/XMOS/PLLSELECT: IC403.100, IC405.6, R413.2
/XMOS/PLLSYNC: IC403.30, IC406.1
/XMOS/QSPI_D0: IC403.31, IC408.5
/XMOS/QSPI_D1: IC403.33, IC408.2
/XMOS/QSPI_D2: IC403.34, IC408.3
/XMOS/QSPI_D3: IC403.35, IC408.7
/XMOS/RST_N: IC401.4, IC401.6, IC403.123, IC403.124, R406.1
/XMOS/SPI_CLK: IC403.28, IC408.6
/XMOS/SPI_CS: IC403.27, IC408.1, R410.2
/XMOS/TCK: IC403.128, X402.9
/XMOS/TDI: IC403.2, X402.5
/XMOS/TDO: IC403.1, X402.13
/XMOS/TMS: IC403.127, X402.7
/XMOS/USBD_N: IC403.47, X401.2
/XMOS/USBD_P: IC403.46, X401.3
/XMOS/VBUS: C411.2, D401.1, IC403.45, R418.2
/XMOS/WCLKSEL: IC403.95, IC406.6, R414.2
/XMOS/XL_DN0: IC403.9, X402.14
/XMOS/XL_DN1: IC403.8, X402.18
/XMOS/XL_UP0: R408.2, X402.10
/XMOS/XL_UP1: R409.2, X402.6
/XMOS/XMCLK: IC403.13, IC403.66, R411.1
/XMOS/XSYS_RST_N: IC401.3, R421.1, X402.15
/xBCLK: R102.7, R104.5, R407.3
/xLRCK: R102.8, R105.8, R407.4
/xSCL: IC403.37, IC404.9, R416.2
/xSDA: IC403.38, IC404.10, R417.2
/xTDMIN: R104.6, R407.2
/xTDMOUT: IC101.62, R407.1
/~RST: IC101.24, IC104.2, IC205.28, IC305.48, IC401.1, R115.2, R405.1
/~USBRST: IC501.36, R114.1, X104.6
GND: C101.2, C102.2, C104.2, C105.2, C107.2, C108.2, C109.2, C110.2, C111.2, C112.2, C113.2, C114.2, C115.2, C116.2, C117.2, C118.2, C119.2, C120.2, C121.2, C122.2, C123.2, C124.2, C125.2, C126.2, C127.2, C128.2, C129.2, C130.2, C131.2, C132.2, C133.2, C134.2, C135.2, C136.2, C137.2, C138.2, C205.2, C206.2, C213.1, C219.2, C220.2, C221.2, C222.2, C229.2, C230.2, C233.2, C234.2, C236.2, C241.2, C242.2, C244.1, C246.2, C249.2, C250.2, C257.2, C258.2, C259.2, C260.2, C261.2, C262.2, C263.2, C264.2, C273.2, C274.2, C275.2, C276.2, C277.2, C278.2, C279.2, C280.2, C282.1, C283.1, C284.1, C286.1, C287.1, C288.1, C313.2, C320.2, C321.2, C328.2, C329.2, C336.2, C337.2, C344.2, C345.2, C352.2, C353.2, C360.2, C361.2, C362.2, C363.2, C364.2, C365.2, C366.2, C367.2, C368.2, C369.2, C370.2, C371.2, C372.2, C373.2, C374.2, C375.2, C376.2, C377.2, C401.1, C402.2, C403.1, C404.1, C405.1, C406.1, C407.1, C408.1, C409.1, C410.1, C411.1, C412.1, C413.1, C414.1, C415.1, C416.2, C417.2, C418.2, C419.2, C420.2, C421.2, C422.2, C423.2, C424.2, C425.2, C426.2, C427.2, C428.2, C429.2, C430.2, C431.2, C432.2, C433.2, C434.2, C435.2, C436.2, C437.2, C438.2, C439.2, C440.2, C441.2, C501.1, C502.1, C503.1, C504.2, C506.2, C507.2, C508.2, IC101.1, IC101.6, IC101.14, IC101.17, IC101.19, IC101.25, IC101.32, IC101.33, IC101.36, IC101.37, IC101.54, IC101.55, IC101.72, IC101.73, IC102.4, IC103.2, IC104.1, IC105.1, IC106.1, IC107.1, IC201.4, IC202.4, IC203.4, IC204.4, IC205.1, IC205.5, IC205.12, IC205.16, IC205.20, IC205.23, IC205.26, IC205.32, IC205.35, IC205.46, IC205.47, IC205.49, IC205.50, IC205.51, IC205.53, IC205.55, IC205.58, IC205.61, IC205.65, IC206.4, IC207.4, IC208.4, IC209.4, IC301.4, IC302.4, IC303.4, IC304.4, IC305.5, IC305.6, IC305.7, IC305.8, IC305.9, IC305.10, IC305.11, IC305.12, IC305.15, IC305.16, IC305.20, IC305.26, IC305.30, IC305.35, IC305.41, IC305.46, IC305.49, IC306.4, IC307.4, IC308.4, IC309.4, IC401.2, IC402.2, IC403.104, IC403.129, IC404.2, IC404.8, IC405.2, IC406.2, IC407.2, IC408.4, IC409.1, IC410.2, IC501.1, IC501.15, IC501.38, IC501.39, IC502.1, JP101.2, OSC401.2, R115.1, R374.1, R375.1, R376.1, R377.1, R378.1, R379.1, R380.1, R381.1, R382.1, R383.1, R384.1, R385.1, R386.1, R387.1, R388.1, R389.1, R413.1, R414.1, R415.2, R418.1, R420.2, SW501.1, X101.2, X101.4, X101.6, X101.8, X101.10, X101.12, X102.2, X102.4, X102.6, X102.8, X102.10, X102.12, X102.14, X102.16, X103.3, X104.10, X105.3, X105.4, X106.2, X201.3, X201.6, X201.9, X201.12, X201.15, X201.18, X201.21, X201.24, X301.3, X301.6, X301.9, X301.12, X301.15, X301.18, X301.21, X301.24, X401.4, X401.5, X402.4, X402.8, X402.12, X402.16, X402.20, X501.1, X502.1, X503.1, X504.1, X504.6, Y101.3
unnamed: C101.1, C102.1, FER101.2, IC101.7
unnamed: C103.1, C104.1, C105.1, C106.1, FER102.2, IC101.15
unnamed: C103.2, R106.1
unnamed: C106.2, IC101.16, R106.2
unnamed: C107.1, IC101.21, Y101.1
unnamed: C108.1, R108.2, Y101.2
unnamed: C111.1, IC103.8
unnamed: C202.1, IC202.2, R202.2, R204.2
unnamed: C202.2, IC202.1, R206.2
unnamed: C203.1, R207.1
unnamed: C204.1, R208.1
unnamed: C207.1, IC201.2, R201.2, R203.2
unnamed: C207.2, IC201.1, R205.2
unnamed: C208.1, IC202.3, R208.2, R210.2
unnamed: C208.2, C214.1, IC202.7, R268.2
unnamed: C209.1, IC201.3, R207.2, R209.2
unnamed: C209.2, C281.1, IC201.7, R211.2
unnamed: C211.1, R203.1
unnamed: C212.1, R204.1
unnamed: C214.2, IC202.6, R212.2, R267.1
unnamed: C215.1, IC203.2, R219.2, R221.2
unnamed: C215.2, IC203.1, R223.2
unnamed: C216.1, IC204.2, R220.2, R222.2
unnamed: C216.2, IC204.1, R224.2
unnamed: C217.1, R229.1
unnamed: C218.1, R230.1
unnamed: C219.1, C220.1, IC205.62, R218.1
unnamed: C223.1, IC203.3, R229.2, R231.2
unnamed: C223.2, C231.1, IC203.7, R270.2
unnamed: C224.1, IC204.3, R230.2, R232.2
unnamed: C224.2, C232.1, IC204.7, R272.2
unnamed: C227.1, R221.1
unnamed: C228.1, R222.1
unnamed: C229.1, C230.1, IC205.6, R228.1
unnamed: C231.2, IC203.6, R233.2, R269.1
unnamed: C232.2, IC204.6, R234.2, R271.1
unnamed: C233.1, C234.1, IC205.11, R238.1
unnamed: C235.1, IC206.2, R240.2, R241.2
unnamed: C235.2, IC206.1, R242.2
unnamed: C237.1, R243.1
unnamed: C238.1, R252.1
unnamed: C239.1, IC206.3, R243.2, R244.2
unnamed: C239.2, C243.1, IC206.7, R248.2
unnamed: C241.1, C242.1, IC205.19, R246.1
unnamed: C243.2, IC206.6, R245.2, R247.1
unnamed: C245.1, IC207.2, R249.2, R250.2
unnamed: C245.2, IC207.1, R251.2
unnamed: C247.1, R241.1
unnamed: C248.1, R250.1
unnamed: C249.1, C250.1, IC205.27
unnamed: C251.1, IC207.3, R252.2, R273.2
unnamed: C251.2, C285.1, IC207.7, R276.2
unnamed: C253.1, IC208.2, R253.2, R255.2
unnamed: C253.2, IC208.1, R257.2
unnamed: C254.1, IC209.2, R254.2, R256.2
unnamed: C254.2, IC209.1, R258.2
unnamed: C255.1, R259.1
unnamed: C256.1, R260.1
unnamed: C265.1, IC208.3, R259.2, R261.2
unnamed: C265.2, C271.1, IC208.7, R278.2
unnamed: C266.1, IC209.3, R260.2, R262.2
unnamed: C266.2, C272.1, IC209.7, R280.2
unnamed: C269.1, R255.1
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

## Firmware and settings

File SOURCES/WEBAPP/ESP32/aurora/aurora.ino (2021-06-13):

#include <Wire.h>
#include <WiFi.h>
#include <ESPAsyncWebServer.h>
#include <SPIFFS.h>
#include "AsyncJson.h"
#include <ArduinoJson.h>
#include "soc/timer_group_struct.h"
#include "soc/timer_group_reg.h"

#include "hwconfig.h"
#include "AK4458.h"
#include "AK5558.h"

#if HAVE_ROTARYENCODER
#include "rotaryencoder.h"
#endif

#if HAVE_IRRECEIVER
#include <IRremote.h>
#endif

/**
 * Routines which originally belonged to aurora.ino,
 *  but have been moved to their own files
 */
#include "config.h"
#include "settings.h"
#include "adau1452.h"
#include "addons.h"
#include "display.h"
#include "plugin.h"
#include "web.h"
#include "display.h"

/**
 * These are required for the espmake32 automatic library resolver
 * It's less powerful than the one from the Arduino IDE.
 * The if-guards can stay
 * see https://github.com/plerup/makeEspArduino
 */
#if 0
#include <FS.h>
#include <WebServer.h>
#include <AsyncTCP.h>
#include <u8g2.h>
#endif

File fileDspProgram;

bool changeWifiState = false;

//------------------------------------------------------------------------------
//
// Rotary Encoder
//
//------------------------------------------------------------------------------
#if HAVE_ROTARYENCODER
long int lastREval = 0;
long int lastREsw = 0;
#endif

//------------------------------------------------------------------------------
//
// IR Receiver
//
//------------------------------------------------------------------------------
#if HAVE_IRRECEIVER
IRrecv irReceiver( IR_RECEIVER_PIN );
#endif

//==============================================================================
/*! Uploads the firmware from ESP32 SPI flash to DSP.
 */
void uploadDspFirmware( void )
{
  Serial.print( "Init dsp......" );

  if( !SPIFFS.exists( "/dsp.fw" ) )
  {
    Serial.println( "File does not exist yet" );
    return;
  }

  fileDspProgram = SPIFFS.open( "/dsp.fw" );

  uint32_t numBytesToRead = 0;
  byte byteReadMSB;
  byte byteReadLSB;
  uint16_t regaddr;

  if( fileDspProgram )
  {
    size_t len = fileDspProgram.size();
    int cntr = 0;
    while( cntr < len )
    {
      uint8_t byteRead;
      fileDspProgram.read( &byteRead, 1 );
      numBytesToRead = (numBytesToRead << 8) + (uint32_t)byteRead;
      fileDspProgram.read( &byteRead, 1 );
      numBytesToRead = (numBytesToRead << 8) + (uint32_t)byteRead;
      fileDspProgram.read( &byteRead, 1 );
      numBytesToRead = (numBytesToRead << 8) + (uint32_t)byteRead;
      fileDspProgram.read( &byteRead, 1 );
      numBytesToRead = (numBytesToRead << 8) + (uint32_t)byteRead;

      cntr += 4;

      //Serial.print( "numBytesToRead " );
      //Serial.println( numBytesToRead );

      //------------------------------------------------------------------------
      //--- Send register address and value
      //------------------------------------------------------------------------
      if( numBytesToRead > 0 )
      {
        fileDspProgram.read( &byteRead, 1 );
        regaddr = ((uint16_t)byteRead) << 8;
        cntr++;

        fileDspProgram.read( &byteRead, 1 );
        regaddr += byteRead;
        cntr++;

        if( numBytesToRead == 4 )
        {
          fileDspProgram.read( &byteReadMSB, 1 );
          cntr++;
          fileDspProgram.read( &byteReadLSB, 1 );
          cntr++;

          if( regaddr == 0x0000 )
            delay( 500 );
          else
          {
            ADAU1452_WRITE_REGISTER( regaddr, byteReadMSB, byteReadLSB );
            if( cntr % 4096 == 0 )
              Serial.print( "." );
            /*if( cntr < 1000 )
            {
              Serial.print( cntr );
              Serial.print( " ");
              Serial.print(regaddr, HEX);
              Serial.print(" ");
              Serial.print( byteReadMSB, HEX );
              Serial.println( byteReadLSB, HEX );
            }*/
          }
        }
        else if( numBytesToRead > 4 )
        {
          uint16_t addr = regaddr;
          byte val[4];

          for( uint32_t ii = 0; ii < numBytesToRead - 2; ii = ii + 4 )
          {
            fileDspProgram.read( &(val[0]), 1 );
            fileDspProgram.read( &(val[1]), 1 );
            fileDspProgram.read( &(val[2]), 1 );
            fileDspProgram.read( &(val[3]), 1 );
            cntr += 4;
            ADAU1452_WRITE_BLOCK( addr, val, 4 );
            if( cntr % 4096 == 0 )
              Serial.print( "." );
            /*if( cntr < 1000 )
            {
              Serial.print( cntr );
              Serial.print( " ");
              Serial.print(addr, HEX);
              Serial.print(" ");
              Serial.println(*(uint32_t*)val, HEX );
            }*/
            addr++;
          }
        }
        else
        {
          Serial.print( "[ERROR] Bad number of bytes: " );
          Serial.println( numBytesToRead );
        }
      }
    }
    int file_size = fileDspProgram.size();

    fileDspProgram.close();
    Serial.println( "[OK]" );
    Serial.print( "File size: " );
    Serial.println( file_size );
  }
  else
    Serial.println( "\n[ERROR] Failed to open file dsp.fw" );
}

//==============================================================================
/*! Wifi connection task
 *
 */
void myWiFiTask(void *pvParameters)
{
  wl_status_t state;
  bool firstConnectAttempt = true;
  bool myWiFiFirstConnect = true;
  int cntrAuthFailure = 0;
  IPAddress ip(192, 168, 5, 1);
  IPAddress subnet(255, 255, 255, 0);

  WiFi.mode(WIFI_AP_STA);
  WiFi.setHostname( "freeDSP-aurora" );
  // Start access point
  if( Settings.pwdap.length() > 0 )
  {
    Serial.print( "AP password protected " );
    Serial.println( Settings.apname );
    WiFi.softAP( Settings.apname.c_str(), Settings.pwdap.c_str() );
  }
  else
  {
    Serial.print( "AP open: " );
    Serial.println( Settings.apname );
    WiFi.softAP( Settings.apname.c_str() );
  }
  delay(100);

  if( !WiFi.softAPConfig( ip, ip, subnet ) )
    Serial.println("AP Config Failed");

  // Start server
  server.begin();

  while (true)
  {
    if( (Settings.ssid.length() > 0) &&  (cntrAuthFailure < 10) )
    {
      state = WiFi.status();
      if( state != WL_CONNECTED )
      {
        //if (state == WL_NO_SHIELD)
        if( firstConnectAttempt )
        {
          firstConnectAttempt = false;
          Serial.print( "Connecting to " );
          Serial.println( Settings.ssid.c_str() );
          WiFi.begin(Settings.ssid.c_str(), Settings.password.c_str());
          cntrAuthFailure++;
        }
        else if( state == WL_IDLE_STATUS )
        {
          Serial.println( "Idle" );
        }
        else if( state == WL_NO_SSID_AVAIL )
        {
          Serial.println( "No SSID available" );
        }
        else if( state == WL_CONNECTION_LOST )
        {
          Serial.println("WiFi connection lost");
          WiFi.disconnect(true);
          cntrAuthFailure++;
        }
        // else if( state == WL_SCAN_COMPLETED )
        else if( state == WL_CONNECT_FAILED )
        {
          Serial.println("WiFi connection failed");
          WiFi.disconnect(true);
          cntrAuthFailure++;
        }
        else if( state == WL_DISCONNECTED )
        {
          if (!myWiFiFirstConnect)
          {
            myWiFiFirstConnect = true;
            Serial.println( "WiFi disconnected" );
          }
          Serial.println("No Connection -> Wifi Reset");
          WiFi.persistent(false);
          WiFi.disconnect();
          WiFi.mode(WIFI_OFF);
          WiFi.mode(WIFI_AP_STA);
          delay(1000);
          // WiFi.config(ip, gateway, subnet); // Only for fix IP needed
          WiFi.begin(Settings.ssid.c_str(), Settings.password.c_str());
          delay(3000);
          cntrAuthFailure++;
        }
        vTaskDelay (250); // Check again in about 250ms
      }
      else // We have connection
      {
        if( myWiFiFirstConnect ) // Report only once
        {
          myWiFiFirstConnect = false;
          cntrAuthFailure = 0;
          Serial.println( "Connected" );
          Serial.print( "IP address: " );
          Serial.println( WiFi.localIP() );
          Serial.println( WiFi.getHostname() );
          needUpdateUI = true;
        }
        vTaskDelay (5000); // Check again in about 5s
      }
    }
    else
      vTaskDelay (5000);
  }
}


//==============================================================================
/*! Arduino Setup
 *
 */
void setup()
{
  Serial.begin(115200);
  Serial.println( "AURORA Debug Log" );
  Serial.println( VERSION_STR );

  //----------------------------------------------------------------------------
  //--- Init Rotary Encoder Handling
  //----------------------------------------------------------------------------
  #if HAVE_ROTARYENCODER
  rotaryEncoder.init();
  lastREsw = rotaryEncoder.getSwitchValue();
  lastREval = rotaryEncoder.getRotationValue();
  #endif

  //----------------------------------------------------------------------------
  //--- Is user pressing the rotary encoder switch during boot?
  //----------------------------------------------------------------------------
  //rotaryEncoder.init();
  //pinMode( ROTARYENCODER_PINSW, INPUT_PULLUP );
  if( !digitalRead( ROTARYENCODER_PINSW ) )
    changeWifiState = true;

  //----------------------------------------------------------------------------
  //--- Configure I2C
  //----------------------------------------------------------------------------
  Wire.begin( I2C_SDA_PIN, I2C_SCL_PIN );
  Wire.setClock( 100000 );
  delay( 100 );

  //----------------------------------------------------------------------------
  //--- Scan for I2C display connected?
  //----------------------------------------------------------------------------
  Wire.beginTransmission( SH1106_I2C_ADDR );
  uint8_t ec = Wire.endTransmission( true );
  if( ec == 0 )
  {
    Serial.println( "Detected SH1106 display" );
    haveDisplay = true;
  }
  else
    haveDisplay = false;

  //----------------------------------------------------------------------------
  //--- Init Display (if present)
  //----------------------------------------------------------------------------
  if( haveDisplay )
  {
    myDisplay.begin();
    myDisplay.drawBootScreen();
  }

  // wait until everything is stable
  // might be a bit to defensive
  delay( 2000 );

  //----------------------------------------------------------------------------
  //--- Configure DAC
  //----------------------------------------------------------------------------
  Serial.println( "Config DAC" );
  configDAC();

  //----------------------------------------------------------------------------
  //--- Configure ADC
  //----------------------------------------------------------------------------
  Serial.println( "Config ADC" );
  configADC();

  //----------------------------------------------------------------------------
  //--- Start SPIFFS
  //----------------------------------------------------------------------------
  if( !SPIFFS.begin( true ) )
  {
    Serial.println("An Error has occurred while mounting SPIFFS");
    return;
  }

  //--- check for old stuff (version == 1.x.x)
  String fileName = "/dspfw.hex";
  if( SPIFFS.exists( fileName ) )
  {
    if( SPIFFS.remove( fileName ) )
      Serial.println( fileName + " deleted." );
    else
      Serial.println( "[ERROR] Deleting " + fileName );
  }
  fileName = "/dspparam.001";
  if( SPIFFS.exists( fileName ) )
  {
    if( SPIFFS.remove( fileName ) )
      Serial.println( fileName + " deleted." );
    else
      Serial.println( "[ERROR] Deleting " + fileName );
  }
  fileName = "/dspparam.002";
  if( SPIFFS.exists( fileName ) )
  {
    if( SPIFFS.remove( fileName ) )
      Serial.println( fileName + " deleted." );
    else
      Serial.println( "[ERROR] Deleting " + fileName );
  }
  fileName = "/dspparam.003";
  if( SPIFFS.exists( fileName ) )
  {
    if( SPIFFS.remove( fileName ) )
      Serial.println( fileName + " deleted." );
    else
      Serial.println( "[ERROR] Deleting " + fileName );
  }
  fileName = "/dspparam.004";
  if( SPIFFS.exists( fileName ) )
  {
    if( SPIFFS.remove( fileName ) )
      Serial.println( fileName + " deleted." );
    else
      Serial.println( "[ERROR] Deleting " + fileName );
  }

  Serial.print( "Free disk space: " );
  Serial.print( (SPIFFS.totalBytes() - SPIFFS.usedBytes()) / 1024 );
  Serial.println( "KiB" );

  File root = SPIFFS.open("/");
  File file = root.openNextFile();
  while(file)
  {
    Serial.print( file.name() );
    Serial.print( " " );
    Serial.print( file.size() );
    Serial.println( " Bytes" );
    file = root.openNextFile();
  }

  //----------------------------------------------------------------------------
  //--- Read settings file
  //----------------------------------------------------------------------------
  readSettings();
  changeChannelSummationADC();
  if( changeWifiState )
  {
    Serial.print( F("Changing WiFi status......") );
    Settings.wifiOn = Settings.wifiOn ? false : true;
    writeSettings();
    Serial.println( F("[OK]") );
  }

  Serial.print( F("Init user parameter......") );
  initUserParams();
  Serial.println( F("[OK]") );
  readPluginMeta();

  //----------------------------------------------------------------------------
  //--- Configure AddOn
  //----------------------------------------------------------------------------
  updateAddOn();

  //----------------------------------------------------------------------------
  //--- Upload program to DSP
  //----------------------------------------------------------------------------
  uploadDspFirmware();

  //----------------------------------------------------------------------------
  //--- Upload user parameters to DSP
  //----------------------------------------------------------------------------
  uploadUserParams();

  //----------------------------------------------------------------------------
  //--- Configure Webserver
  //----------------------------------------------------------------------------
  setupWebserver();

  //----------------------------------------------------------------------------
  //--- Configure ESP for WiFi access
  //----------------------------------------------------------------------------
  // Create a connection task with 8kB stack on core 0
  if( Settings.wifiOn )
    xTaskCreatePinnedToCore(myWiFiTask, "myWiFiTask", 8192, NULL, 3, NULL, 0);

  //----------------------------------------------------------------------------
  //--- Enable Volume Potentiometer
  //----------------------------------------------------------------------------
  enableVolPot();

  //----------------------------------------------------------------------------
  //--- Init IR Receiver
  //----------------------------------------------------------------------------
  #if HAVE_IRRECEIVER
  irReceiver.enableIRIn();
  #endif

  resetDAC( false );

  updateUI();

  lastREsw = rotaryEncoder.getSwitchValue();
  lastREval = rotaryEncoder.getRotationValue();

  Serial.println( "Ready" );
}


String getValue(String data, char separator, int index)
{
    int found = 0;
    int strIndex[] = { 0, -1 };
    int maxIndex = data.length() - 1;

    for (int i = 0; i <= maxIndex && found <= index; i++) {
        if (data.charAt(i) == separator || i == maxIndex) {
            found++;
            strIndex[0] = strIndex[1] + 1;
            strIndex[1] = (i == maxIndex) ? i+1 : i;
        }
    }
    return found > index ? data.substring(strIndex[0], strIndex[1]) : "";
}

//==============================================================================
/*! Arduino Main Loop
 *
 */
void loop()
{
  static String currentSerialLine = "";

  TIMERG0.wdt_wprotect=TIMG_WDT_WKEY_VALUE;
  TIMERG0.wdt_feed=1;
  TIMERG0.wdt_wprotect=0;

  if (Serial.available() > 0) {

    char input = Serial.read();

    if(input != '\r' && input != '\n')
    {
      currentSerialLine += input;
    }
    if(input == '\n')
    {
      Serial.println(currentSerialLine);

      String handler = getValue(currentSerialLine, '|', 0);
      String data = getValue(currentSerialLine, '|', 1);

      if(handler == "/mvol")
      {
        Serial.println("Setting volume to " + data);
        masterVolume.val = data.toFloat();
        setMasterVolume();
      }

      if(handler == "/input")
      {
        Serial.println("Setting input to " + data);

        String idx_param = getValue(currentSerialLine, '|', 2);
        String sel = getValue(currentSerialLine, '|', 4);

        Serial.println("idx: " + idx_param);
        Serial.println("sel: " + sel);

        softMuteDAC();
        delay(500);

        int idx = idx_param.toInt();

        paramInputs[idx].sel = (uint32_t)strtoul( sel.c_str(), NULL, 16 );

        setInput( idx );

        softUnmuteDAC();
      }

      if(handler == "/addoncfg")
      {
        Serial.println("Configuring addon " + data);

        softMuteDAC();
        delay(500);

        if( Settings.addonid == ADDON_B )
        {
          String i2c1 = getValue(currentSerialLine, '|', 1);
          String i2c2 = getValue(currentSerialLine, '|', 2);
          String i2c3 = getValue(currentSerialLine, '|', 3);

          currentAddOnCfg[0] = (uint8_t)strtoul( i2c1.c_str(), NULL, 16 );
          currentAddOnCfg[1] = (uint8_t)strtoul( i2c2.c_str(), NULL, 16 );
          currentAddOnCfg[2] = (uint8_t)strtoul( i2c3.c_str(), NULL, 16 );

          Wire.beginTransmission( currentAddOnCfg[0]>>1 ); //ADDONB_SPDIFMUX_ADDR
          Wire.write( currentAddOnCfg[1] ); // regaddr
          Wire.write( currentAddOnCfg[2] ); // data
          Wire.endTransmission( true );
        }

        softUnmuteDAC();
      }

      if(handler == "/reset")
      {
        ESP.restart();
      }

      currentSerialLine = "";
    }
  }


  #if HAVE_ROTARYENCODER
  if( rotaryEncoder.getSwitchValue() != lastREsw )
  {
    if( changeWifiState )
      changeWifiState = false;
    else
    {
      editMode++;
      // we may have more then two modes in the future.
      if( editMode > 1 )
        editMode = 0;
      delay( 300 );
      needUpdateUI = true;
    }
    lastREsw = rotaryEncoder.getSwitchValue();
    lastREval = rotaryEncoder.getRotationValue();
  }
  else if( rotaryEncoder.getRotationValue() > lastREval + 1 )
  {
    if( editMode == 0 )
    {
      masterVolume.val += 0.5f;
      if( masterVolume.val > 0.f )
        masterVolume.val = 0.f;
      setMasterVolume();
      lastREval = rotaryEncoder.getRotationValue();
      needUpdateUI = true;
    }
    else if( editMode == 1 )
    {
      myDisplay.drawSwitchingPreset();

      currentPreset++;
      if( currentPreset >= MAX_NUM_PRESETS )
        currentPreset = 0;

      softMuteDAC();
      initUserParams();
      uploadUserParams();
      updateAddOn();
      softUnmuteDAC();

      lastREval = rotaryEncoder.getRotationValue();
      needUpdateUI = true;
    }
  }
  else if( rotaryEncoder.getRotationValue() < lastREval - 1 )
  {
    if( editMode == 0 )
    {
      masterVolume.val -= 0.5f;
      if( masterVolume.val <= -80.f )
        masterVolume.val = -80.f;
      setMasterVolume();
      lastREval = rotaryEncoder.getRotationValue();
      needUpdateUI = true;
    }
    else if( editMode == 1 )
    {
      myDisplay.drawSwitchingPreset();

      if( currentPreset == 0 )
        currentPreset = MAX_NUM_PRESETS - 1;
      else
        currentPreset--;

      softMuteDAC();
      initUserParams();
      uploadUserParams();
      updateAddOn();
      softUnmuteDAC();

      lastREval = rotaryEncoder.getRotationValue();
      needUpdateUI = true;
    }
  }
  #endif

  #if HAVE_IRRECEIVER
  decode_results irResults;
  if( irReceiver.decode( &irResults ) )
  {
    if( irResults.value == APPLE_REMOTE_UP )
    {
      masterVolume.val += 0.5f;
      if( masterVolume.val > 0.f )
        masterVolume.val = 0.f;
      setMasterVolume();
      needUpdateUI = true;
    }
    else if( irResults.value == APPLE_REMOTE_DOWN )
    {
      masterVolume.val -= 0.5f;
      if( masterVolume.val <= -80.f )
        masterVolume.val = -80.f;
      setMasterVolume();
      needUpdateUI = true;
    }
    else if( irResults.value == APPLE_REMOTE_LEFT )
    {
      myDisplay.drawSwitchingPreset();

      if( currentPreset == 0 )
        currentPreset = MAX_NUM_PRESETS - 1;
      else
        currentPreset--;

      softMuteDAC();
      initUserParams();
      uploadUserParams();
      updateAddOn();
      softUnmuteDAC();

      needUpdateUI = true;
    }
    else if( irResults.value == APPLE_REMOTE_RIGHT )
    {
      myDisplay.drawSwitchingPreset();

      currentPreset++;
      if( currentPreset >= MAX_NUM_PRESETS )
        currentPreset = 0;

      softMuteDAC();
      initUserParams();
      uploadUserParams();
      updateAddOn();
      softUnmuteDAC();

      needUpdateUI = true;
    }
    //else
    //  Serial.println(irResults.value, HEX);
    irReceiver.resume();
  }
  #endif

  if( needUpdateUI )
  {
    updateUI();
    needUpdateUI = false;
  }

}

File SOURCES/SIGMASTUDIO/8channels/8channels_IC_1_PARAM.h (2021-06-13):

/*
 * File:           Z:\Documents\freeDSP\freeDSP-aurora\SOURCES\SIGMASTUDIO\8channels\8channels_IC_1_PARAM.h
 *
 * Created:        Thursday, August 13, 2020 4:24:55 PM
 * Description:    8channels:IC 1 parameter RAM definitions.
 *
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
 * This software may only be used to program products purchased from
 * Analog Devices for incorporation by you into audio products that
 * are intended for resale to audio product end users. This software
 * may not be distributed whole or in any part to third parties.
 *
 * Copyright ©2020 Analog Devices, Inc. All rights reserved.
 */
#ifndef __8CHANNELS_IC_1_PARAM_H__
#define __8CHANNELS_IC_1_PARAM_H__


/* Module SafeLoadModule - SafeLoadModule*/
#define MOD_SAFELOADMODULE_COUNT                       7
#define MOD_SAFELOADMODULE_DEVICE                      "IC1"
#define MOD_SAFELOADMODULE_DATA_SAFELOAD0_ADDR         18832
#define MOD_SAFELOADMODULE_DATA_SAFELOAD1_ADDR         18833
#define MOD_SAFELOADMODULE_DATA_SAFELOAD2_ADDR         18834
#define MOD_SAFELOADMODULE_DATA_SAFELOAD3_ADDR         18835
#define MOD_SAFELOADMODULE_DATA_SAFELOAD4_ADDR         18836
#define MOD_SAFELOADMODULE_ADDRESS_SAFELOAD_ADDR       18837
#define MOD_SAFELOADMODULE_NUM_SAFELOAD_ADDR           18838

/* Module Shift1 - Arithmetic Shift*/
#define MOD_SHIFT1_COUNT                               1
#define MOD_SHIFT1_DEVICE                              "IC1"
#define MOD_SHIFT1_BITSHIFTADAU145XALG1SHIFTBITS_ADDR  18839
#define MOD_SHIFT1_BITSHIFTADAU145XALG1SHIFTBITS_FIXPT 0x0000000E
#define MOD_SHIFT1_BITSHIFTADAU145XALG1SHIFTBITS_VALUE SIGMASTUDIOTYPE_INTEGER_CONVERT(14)
#define MOD_SHIFT1_BITSHIFTADAU145XALG1SHIFTBITS_TYPE  SIGMASTUDIOTYPE_INTEGER

/* Module HP1_1 - General Eq (2nd order)*/
#define MOD_HP1_1_COUNT                                5
#define MOD_HP1_1_DEVICE                               "IC1"
#define MOD_HP1_1_ALG0_STAGE0_B2_ADDR                  19200
#define MOD_HP1_1_ALG0_STAGE0_B2_VALUE                 SIGMASTUDIOTYPE_8_24_CONVERT(0)
#define MOD_HP1_1_ALG0_STAGE0_B2_TYPE                  SIGMASTUDIOTYPE_8_24
#define MOD_HP1_1_ALG0_STAGE0_B1_ADDR                  19201
#define MOD_HP1_1_ALG0_STAGE0_B1_VALUE                 SIGMASTUDIOTYPE_8_24_CONVERT(0)
#define MOD_HP1_1_ALG0_STAGE0_B1_TYPE                  SIGMASTUDIOTYPE_8_24
#define MOD_HP1_1_ALG0_STAGE0_B0_ADDR                  19202
#define MOD_HP1_1_ALG0_STAGE0_B0_VALUE                 SIGMASTUDIOTYPE_8_24_CONVERT(1)
#define MOD_HP1_1_ALG0_STAGE0_B0_TYPE                  SIGMASTUDIOTYPE_8_24
#define MOD_HP1_1_ALG0_STAGE0_A2_ADDR                  19203
#define MOD_HP1_1_ALG0_STAGE0_A2_VALUE                 SIGMASTUDIOTYPE_8_24_CONVERT(0)
#define MOD_HP1_1_ALG0_STAGE0_A2_TYPE                  SIGMASTUDIOTYPE_8_24
#define MOD_HP1_1_ALG0_STAGE0_A1_ADDR                  19204
#define MOD_HP1_1_ALG0_STAGE0_A1_VALUE                 SIGMASTUDIOTYPE_8_24_CONVERT(0)
#define MOD_HP1_1_ALG0_STAGE0_A1_TYPE                  SIGMASTUDIOTYPE_8_24

/* Module HP2_1 - General Eq (2nd order)*/
#define MOD_HP2_1_COUNT                                5
#define MOD_HP2_1_DEVICE                               "IC1"
#define MOD_HP2_1_ALG0_STAGE0_B2_ADDR                  19205
#define MOD_HP2_1_ALG0_STAGE0_B2_VALUE                 SIGMASTUDIOTYPE_8_24_CONVERT(0)
#define MOD_HP2_1_ALG0_STAGE0_B2_TYPE                  SIGMASTUDIOTYPE_8_24
#define MOD_HP2_1_ALG0_STAGE0_B1_ADDR                  19206
#define MOD_HP2_1_ALG0_STAGE0_B1_VALUE                 SIGMASTUDIOTYPE_8_24_CONVERT(0)
#define MOD_HP2_1_ALG0_STAGE0_B1_TYPE                  SIGMASTUDIOTYPE_8_24
#define MOD_HP2_1_ALG0_STAGE0_B0_ADDR                  19207
#define MOD_HP2_1_ALG0_STAGE0_B0_VALUE                 SIGMASTUDIOTYPE_8_24_CONVERT(1)
#define MOD_HP2_1_ALG0_STAGE0_B0_TYPE                  SIGMASTUDIOTYPE_8_24
#define MOD_HP2_1_ALG0_STAGE0_A2_ADDR                  19208
#define MOD_HP2_1_ALG0_STAGE0_A2_VALUE                 SIGMASTUDIOTYPE_8_24_CONVERT(0)
#define MOD_HP2_1_ALG0_STAGE0_A2_TYPE                  SIGMASTUDIOTYPE_8_24
#define MOD_HP2_1_ALG0_STAGE0_A1_ADDR                  19209
#define MOD_HP2_1_ALG0_STAGE0_A1_VALUE                 SIGMASTUDIOTYPE_8_24_CONVERT(0)
#define MOD_HP2_1_ALG0_STAGE0_A1_TYPE                  SIGMASTUDIOTYPE_8_24
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

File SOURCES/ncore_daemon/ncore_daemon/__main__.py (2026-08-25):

from __future__ import annotations

import argparse
import logging

import uvicorn

from ncore_daemon.app import create_app
from ncore_daemon.config import load_settings


def main() -> None:
    parser = argparse.ArgumentParser(description="Ncore / aurora control daemon")
    parser.add_argument("--config", default=None, help="Path to config.yaml")
    parser.add_argument("--dry-run", action="store_true", help="No GPIO/serial/IR")
    args = parser.parse_args()

    logging.basicConfig(
        level=logging.INFO,
        format="%(asctime)s %(levelname)s %(name)s: %(message)s",
    )
    settings = load_settings(args.config)
    if args.dry_run:
        settings.dry_run = True

    app = create_app(settings)
    uvicorn.run(app, host=settings.host, port=settings.port)


if __name__ == "__main__":
    main()

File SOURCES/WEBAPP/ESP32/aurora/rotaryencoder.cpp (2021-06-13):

#include <Arduino.h>

#include "hwconfig.h"
#include "rotaryencoder.h"

portMUX_TYPE gpioMux = portMUX_INITIALIZER_UNLOCKED;

RotaryEncoder rotaryEncoder;

void IRAM_ATTR isrRotaryEncoderAB( void )
{
  uint8_t masked_state = rotaryEncoder.getCurrentState() & 0b00000011;

  portENTER_CRITICAL_ISR( &gpioMux );

  if( digitalRead( ROTARYENCODER_PINA ) )
    masked_state |= 0b00000100;
  if( digitalRead( ROTARYENCODER_PINB ) )
    masked_state |= 0b00001000;

  switch( masked_state )
  {
    case 0b00000000:
    case 0b00000101:
    case 0b00001010:
    case 0b00001111:
      break;

    case 0b00000001:
    case 0b00000111:
    case 0b00001000:
    case 0b00001110:
      rotaryEncoder.setRotationValue( rotaryEncoder.getRotationValue() - 1 );
      break;

    case 0b00000010:
    case 0b00000100:
    case 0b00001011:
    case 0b00001101:
      rotaryEncoder.setRotationValue( rotaryEncoder.getRotationValue() + 1 );
      break;

    case 0b00000011:
    case 0b00001100:
      rotaryEncoder.setRotationValue( rotaryEncoder.getRotationValue() - 2 );
      break;

    default:
      rotaryEncoder.setRotationValue( rotaryEncoder.getRotationValue() + 2 );
      break;
  }

  rotaryEncoder.setCurrentState( masked_state >> 2 );
  portEXIT_CRITICAL_ISR( &gpioMux );
}

void IRAM_ATTR isrRotaryEncoderSwitch()
{
 portENTER_CRITICAL_ISR( &gpioMux );
 if( digitalRead( ROTARYENCODER_PINSW ) )
   rotaryEncoder.setSwitchValue( rotaryEncoder.getSwitchValue() + 1 );
 portEXIT_CRITICAL_ISR( &gpioMux );
}

RotaryEncoder::RotaryEncoder( void )
{

}

void RotaryEncoder::init( void )
{
  value = 0;
  sw = 0;
  state = 2;

  pinMode( ROTARYENCODER_PINA, INPUT_PULLUP );
  pinMode( ROTARYENCODER_PINB, INPUT_PULLUP );
  pinMode( ROTARYENCODER_PINSW, INPUT_PULLUP );

  attachInterrupt( ROTARYENCODER_PINA, isrRotaryEncoderAB, CHANGE );
  attachInterrupt( ROTARYENCODER_PINB, isrRotaryEncoderAB, CHANGE );
  attachInterrupt( ROTARYENCODER_PINSW, isrRotaryEncoderSwitch, CHANGE );
}

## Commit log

2026-08-25 Add a Python Ncore daemon for Home Assistant control.
    Replace the Volumio Java bridge with a REST service that drives the aurora DSP, Hypex GPIO, and IR remote, with speaker-safe volume limits for a universal media_player.
    [__main__.py, amp.py, app.py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]
2026-08-26 Add a from-scratch Pi 4 install with HA kiosk on the DSI screen.
    Ship install.sh, systemd for the ncore user, and Chromium autostart so a clean Raspberry Pi OS desktop can run the daemon and show Home Assistant on the 7-inch panel.
